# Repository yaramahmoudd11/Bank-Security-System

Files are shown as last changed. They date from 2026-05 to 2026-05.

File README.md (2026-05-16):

# 🏦 Bank Smart Security System

An AI-powered smart security system for banks and restricted areas using embedded systems, machine learning, IoT, cloud services, Docker deployment, and real-time mobile monitoring.

---

## 📸 Project Overview

The **Bank Smart Security System** is designed to automate security monitoring in restricted areas such as bank rooms, storage areas, locker rooms, and sensitive access zones.

The system combines:

* A **Raspberry Pi Linux-based unit** for camera processing, face recognition, server communication, GPIO handling, Docker deployment, and cloud integration.
* A **PIC16F877A microcontroller-based unit** for low-level sensor reading, voltage monitoring, relay control, buzzer control, LED indication, and lock control.
* A **Flutter mobile application** for real-time alerts, door control, voltage visualization, outage statistics, and event review.
* **Supabase** for database, storage, and real-time streams.
* **Firebase Cloud Messaging** for push notifications.
* **HuggingFace** for hosting the trained face-recognition classifier/model files.
* **Docker Hub** for Raspberry Pi deployment.

The system detects unauthorized access, after-hours motion intrusion, and power-fault conditions, then sends real-time alerts to the manager through the mobile application.

---

## 🧠 High-Level System Flow

### Face Recognition Flow

```text
Camera → Face Detection → ArcFace Embedding → SVC Classifier
                                                      |
                                                      v
                                              Known? → Log access
                                              Unknown? → Alert App → User decides action
                                                                          |
                                                                          v
                                                              HTTP request to Pi → Alarm / Lock
```

### Sensor and Power Monitoring Flow

```text
PIR Sensor → PIC16F877A → Close door + Light room → Signal Pi → Capture image → Alert App
Voltage Sensor → PIC16F877A → Power statistics → Raspberry Pi → Alert App
```

---

## ✅ Main Features

* Face recognition access control
* Authorized and unauthorized person classification
* PIR motion detection
* Voltage and power-fault monitoring
* Relay-controlled solenoid lock
* Buzzer and LED alarm indicators
* Raspberry Pi camera evidence capture
* Supabase cloud database integration
* Supabase storage for alert images
* Firebase Cloud Messaging notifications
* Real-time mobile alert streaming
* Remote door lock/unlock control
* Live voltage monitoring and visualization
* Power stability percentage
* Outage rate percentage
* Average voltage display
* Backup battery activity indication
* Alert status tracking: `new` and `reviewed`
* Docker deployment on Raspberry Pi
* HuggingFace-hosted face-recognition model files

---

## 🏗️ Final System Architecture

```text
Camera / Sensors
      |
      v
Raspberry Pi Unit + PIC16F877A Unit
      |
      v
Face Recognition + Sensor Processing
      |
      v
Security Decision Logic
      |
      v
Supabase Database + Supabase Storage
      |
      v
Firebase Cloud Messaging
      |
      v
Flutter Mobile Application
      |
      v
Manager Action:
- View alert
- Review alert
- Lock door
- Unlock door
- Ignore alert
```

---

## 🧩 Hardware Components

### Raspberry Pi / Linux-Based Unit

* Raspberry Pi 4
* Camera module
* Python runtime
* OpenCV
* ONNX face recognition models
* Network connection
* GPIO pins for PIR, power outage signal, alarm, and door lock
* Flask HTTP server interface for lock and alert actions
* Docker runtime for containerized deployment

### PIC16F877A Microcontroller Unit

* PIC16F877A microcontroller
* PIR motion sensor
* Voltage sensor module
* 2-channel relay module
* Solenoid lock
* Buzzer
* LEDs
* Logic level converter
* External power supply
* Backup battery switching circuit

---
## 🗂️ Repository Structure

```text
Bank-Security-System/
│
├── README.md
│
├── demo/
│   ├── demo_video_link.txt
│   └── .gitkeep
│
├── docs/
│   ├── diagrams/
│   ├── references/
│   └── schematics/
│
├── face_systems/
│   ├── main.py
│   ├── down.py
│   └── models/
│
├── hardware/
│   ├── pcb/
│   ├── pic_microcontroller/
│   └── wiring_diagrams/
│
├── mobile_app/
│   └── bank_alert_app/
│       ├── lib/
│       ├── android/
│       ├── ios/
│       ├── assets/images/
│       ├── supabase/
│       ├── test/
│       ├── web/
│       ├── windows/
│       ├── linux/
│       ├── macos/
│       ├── pubspec.yaml
│       └── pubspec.lock
│
└── pi/
    ├── Dockerfile
    ├── requirements.txt
    └── run.sh
```

---

## 🧠 Raspberry Pi 4 Unit

The Raspberry Pi acts as the main intelligent processing unit. It handles camera capture, face recognition, GPIO interaction, mobile app commands, Supabase communication, and alert generation.

### Main Tasks

| Task | Description |
| --- | --- |
| Camera loop | Captures frames continuously using the Pi camera |
| Detection loop | Runs face detection and face recognition |
| GPIO loop | Monitors PIR signal and power outage signal from the PIC |
| Cloud update | Uploads alerts, images, voltage data, and system states to Supabase |
| HTTP server | Receives lock/unlock/alarm commands from the mobile app |

### Flask API Endpoints

| Endpoint | Action |
| --- | --- |
| `GET /alert_action` | Trigger alarm for a short time |
| `GET /lock_on` | Lock the vault/security door |
| `GET /lock_off` | Unlock the vault/security door |

---

## ⚙️ GPIO Pin Map — Raspberry Pi 4

| Pin (BCM) | Role |
| --- | --- |
| GPIO 23 | PIR sensor input |
| GPIO 24 | Power outage signal input from PIC |
| GPIO 18 | Alarm output |
| GPIO 27 | Door lock output |

---

## 🔌 PIC16F877A Microcontroller Unit

The PIC16F877A unit handles low-level embedded control. It reads analog and digital inputs, controls relays, activates alarm outputs, monitors voltage, and controls lock-related outputs.

### PIC Pin Mapping

| PIC Pin | Function |
| --- | --- |
| RA0 / AN0 | Voltage sensor analog input |
| RB1 | PIR motion sensor input / digital security condition |
| RB2 | Additional digital input condition |
| RC6 / TX  | UART transmit to Raspberry Pi |
| RC7 / RX  | UART receive from Raspberry Pi |
| RD0 | Relay / solenoid lock control |
| RD1 | Alarm or status output |
| RD2 | Low-voltage warning output |
| RD3 | Security or motion-related output |
| RD4 | Lock/unlock-related output |

---

## 🧱 PIC Driver-Based Firmware Structure

The PIC firmware is planned to be organized using a driver-based structure for readability and easier debugging.

## 🧪 Embedded Control Logic

### Voltage Monitoring

The voltage sensor is connected to `RA0/AN0`.

If the measured voltage drops below the selected threshold:

* The low-voltage warning output is activated.
* Backup battery indication can be enabled.
* A power-fault condition is triggered.
* The mobile application displays the outage state through cloud updates.

### PIR Motion Detection

If PIR motion is detected in a restricted area:

* The alarm output is activated.
* The Raspberry Pi captures image evidence.
* An intrusion alert is uploaded to Supabase.
* The mobile application receives a real-time notification.

### Lock Control

The solenoid lock is controlled through a relay.

The lock state can be changed by:

* Local embedded logic
* Raspberry Pi decision logic
* Mobile application remote command

---

## 🤖 Machine Learning Pipeline

The system uses camera-based face recognition to detect whether a person is authorized or unauthorized.

### Pipeline

```text
Camera Frame
      |
      v
YuNet Face Detector
      |
      v
Crop Face
      |
      v
ArcFace Embedding Model
      |
      v
512-D Embedding
      |
      v
SVC Classifier
      |
      v
Name / UNKNOWN
```

### Model on HuggingFace

🤗 **HuggingFace Model:** [Hagar633/face-recognition-svc](https://huggingface.co/Hagar633/face-recognition-svc)

### Model Files

| File | Description |
| --- | --- |
| `classifier.pkl` | Trained SVC model saved using joblib |
| `yunet.onnx` | YuNet face detector |
| `w600k_mbf.onnx` | ArcFace embedding model |
| `det_500m.onnx` | Additional detection model |
| `mobilefacenet.onnx` | Lightweight face model |

Download all model files from HuggingFace and place them in the models folder before running.

Recommended model folder:

```text
face_systems/models/
```

### Standalone Classifier Example

```python
import joblib

clf = joblib.load("models/classifier.pkl")
prediction = clf.predict(embedding.reshape(1, -1))
```

Confidence threshold:

```text
0.70
```

Predictions below this threshold are treated as `UNKNOWN`.

---

## 🐳 Docker Setup

### Docker Hub Image

```bash
sudo docker pull hagar633/bank_sys2:latest
```

### Build Locally

```bash
cd raspberry_pi/
sudo docker build -t bank_sys .
```

### Run on Raspberry Pi

```bash
sudo ./run.sh
```

The `run.sh` script mounts Raspberry Pi system libraries and Python virtual environment into the container so hardware dependencies such as `picamera2`, `libcamera`, `GPIO`, and `cv2` can work correctly.

Example run command:

```bash
sudo docker run --privileged --network host \
  -v /dev:/dev \
  -v /run/udev:/run/udev:ro \
  -v /usr:/usr:ro \
  -v /lib:/lib:ro \
  -v /home/pi/venv2:/home/pi/venv2:ro \
  -v /home/pi/bank_sys:/app \
  -e PYTHONPATH=/home/pi/venv2/lib/python3.13/site-packages \
  -e LIBCAMERA_IPA_MODULE_PATH=/usr/lib/arm-linux-gnueabihf/libcamera \
  -e SUPABASE_URL="your_supabase_url" \
  -e SUPABASE_KEY="your_supabase_key" \
  --entrypoint /usr/bin/python3.13 \
  bank_sys /app/mergeall3.py
```

### Push to Docker Hub

```bash
sudo docker login
sudo docker tag bank_sys hagar633/bank_sys2:latest
sudo docker push hagar633/bank_sys2:latest
```

---

## 📦 Dependencies

### Python Dependencies

* `opencv-python` — face detection and embedding preprocessing
* `numpy` — numerical operations
* `scikit-learn` / `joblib` — SVC classifier
* `picamera2` — Raspberry Pi camera interface
* `RPi.GPIO` — GPIO control
* `flask` — HTTP API
* `supabase` — cloud database client
* `requests` — HTTP requests
* `python-dotenv` — environment variables

### System Dependencies

* `libcamera`
* Raspberry Pi OS Bookworm 64-bit
* PIC16F877A with custom firmware
* Docker Engine

---

## 📱 Mobile Application Setup

The mobile application is built using Flutter. It displays alerts, receives notifications, shows voltage statistics, and allows the manager to control the door.

### Required Software

* Flutter SDK
* Android Studio or VS Code
* Android Emulator or Android phone
* Firebase project
* Supabase project

### Installation Steps

Go to the mobile app folder:

```bash
cd Bank-Security-System/mobile_app/bank_alert_app
```

Install dependencies:

```bash
flutter pub get
```

Clean previous builds if needed:

```bash
flutter clean
flutter pub get
```

Run the app:

```bash
flutter run
```

---

## ☁️ Supabase Setup

The app connects to Supabase using:

* Supabase project URL
* Supabase anon key
* `alerts` table
* `door_state` table
* `device_tokens` table
* `voltage sensor` table
* `alerts` storage bucket

### Suggested Tables

#### alerts

| Column | Type | Description |
| --- | --- | --- |
| id | int8 | Alert ID |
| category | text | `access`, `intrusion`, or `power` |
| message | text | Alert message |
| image_path | text | Stored image path |
| source_id  | text | Source unit |
| location | text | Alert location |
| status | text | `new` or `reviewed` |
| created_at | timestamp | Alert creation time |
| extra_data | jsonb | Additional event information |

#### door_state

| Column | Type | Description |
| --- | --- | --- |
| id | int8 | Fixed row ID, usually 1 |
| is_locked | bool | Current lock state |
| updated_at  | timestamp | Last update time |
| updated_by  | text | Source of update |
| last_reason | text | Reason for last state change |

#### device_tokens

| Column | Type | Description |
| --- | --- | --- |
| token | text | FCM device token  |
| platform | text | Device platform |
| updated_at | timestamp | Last token update |

#### voltage sensor

| Column | Type | Description |
| --- | --- | --- |
| id | int8 | Reading ID |
| voltage | float8 | Measured voltage |
| adc_value | int4 | ADC reading |
| status | text | `NORMAL`, `LOW`, or `POWER_OUTAGE` |
| battery_active | bool | Backup battery state |
| created_at | timestamp | Reading time |

---

## 📓 Required Notebook

The final codebase includes:

```text
notebooks/model_finetuning_and_results.ipynb
```

The notebook should document:

* Dataset overview
* Number of enrolled persons
* Number of images per person
* Image preprocessing steps
* Face detection and embedding generation
* Model details
* Recognition threshold
* Similarity score distribution
* Accuracy or evaluation results
* Voltage readings visualization
* Alert category distribution
* Door action statistics
* Inference time analysis
* Power or response-time analysis if measured

---

## ✅ Final Implementation Results

### Access Control

When an unauthorized face is detected:

* The system classifies the person as unauthorized.
* The door remains locked.
* An alert is inserted into the Supabase `alerts` table.
* The captured image is uploaded to Supabase Storage.
* The mobile application displays the alert in the Access tab.
* The manager receives a notification.

### Intrusion Detection

When PIR motion is detected:

* The system triggers an intrusion event.
* Alarm indicators are activated.
* The Raspberry Pi captures image evidence.
* An intrusion alert is sent to the mobile application.
* The manager can review the event and control the door.

### Power Monitoring

When the voltage drops below the defined threshold:

* The PIC detects a low-voltage or outage condition.
* The backup battery indicator is activated.
* A power alert is uploaded to the cloud.
* The mobile app displays the event in the Power tab.
* Live voltage readings are shown in the Voltage tab.

### Mobile Application

The Flutter application provides:

* Splash screen
* Real-time alert list
* Alert details page
* Access alerts tab
* Intrusion alerts tab
* Power alerts tab
* Voltage monitoring tab
* Alert status update
* Door lock/unlock control
* FCM notification support
* Voltage chart
* Power stability percentage
* Outage rate percentage
* Average voltage display
* Battery backup status

---

## 🎬 Demo Scenarios

The following demo scenarios are supported:

1. Authorized user access
2. Unauthorized user detection
3. Motion intrusion detection
4. Power outage detection
5. Remote door lock
6. Remote door unlock
7. Real-time voltage monitoring
8. Mobile notification reception
9. Alert review and status update

---

## 🚀 Running the Full System

### Step 1: Configure Supabase and Firebase

Make sure the following are configured:

* Supabase database tables
* Supabase storage bucket
* Supabase real-time enabled tables
* Firebase Cloud Messaging project
* Flutter Firebase options

### Step 2: Program the PIC

Upload the compiled HEX file to the PIC16F877A.

### Step 3: Start the Raspberry Pi Unit

```bash
cd Bank-Security-System
source venv/bin/activate
python face_systems/main.py
```

### Step 4: Run the Mobile App

```bash
cd mobile_app/bank_alert_app
flutter clean
flutter pub get
flutter run
```

### Step 5: Test the Scenarios

Test the following:

* Face recognition
* Unauthorized access alert
* PIR intrusion alert
* Voltage drop alert
* Door lock command
* Door unlock command
* Notification reception
* Live voltage visualization

---

## 🔐 Security Notes

* Do not publish real Supabase keys, Firebase keys, service account files, or private credentials in a public repository.
* Use `.env` files for local secrets.
* Add secret files to `.gitignore`.
* Use Supabase Row Level Security policies.
* Restrict write access to sensitive tables.
* Validate commands received by the Raspberry Pi before controlling the lock.

Recommended `.gitignore` entries:

```text
.env
*.env
serviceAccountKey.json
firebase-service-account.json
*firebase-adminsdk*.json
google-services.json
GoogleService-Info.plist
node_modules/
__pycache__/
venv/
build/
.dart_tool/
*.log
```

---

## 📚 Documentation

Project documentation is stored in:

```text
docs/
```

It includes:

* System architecture diagram
* Input/output diagram
* Electrical schematic
* PCB documentation
* Reference papers
* Screenshots
* Test results

---

## 🔗 Links

* 🐳 Docker Hub: [hagar633/bank_sys](https://hub.docker.com/r/hagar633/bank_sys2)
* 🤗 HuggingFace Model: [Hagar633/face-recognition-svc](https://huggingface.co/Hagar633/face-recognition-svc)
* 💻 GitHub: [yaramahmoudd11/Bank-Security-System](https://github.com/yaramahmoudd11/Bank-Security-System)

---

## 👥 Authors

* Yara Mahmoud
* Filopater Emad
* Hagar Alsherbiny

---

## 📄 License

This project is developed for educational and academic purposes.

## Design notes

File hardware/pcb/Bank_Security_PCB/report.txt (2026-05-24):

Info: Processing symbol 'C1:Capacitor_THT:C_Disc_D5.0mm_W2.5mm_P5.00mm'.
Info: Processing symbol 'C2:Capacitor_THT:C_Disc_D5.0mm_W2.5mm_P5.00mm'.
Info: Processing symbol 'D1:LED_THT:LED_D5.0mm'.
Info: Processing symbol 'D2:LED_THT:LED_D5.0mm'.
Info: Processing symbol 'J1:Connector_PinHeader_2.54mm:PinHeader_2x20_P2.54mm_Vertical'.
Info: Processing symbol 'J2:Connector_PinHeader_2.54mm:PinHeader_1x03_P2.54mm_Vertical'.
Info: Processing symbol 'J3:Connector_PinHeader_2.54mm:PinHeader_1x03_P2.54mm_Vertical'.
Info: Processing symbol 'J4:Connector_PinHeader_2.54mm:PinHeader_1x03_P2.54mm_Vertical'.
Info: Processing symbol 'J5:TerminalBlock_CUI:TerminalBlock_CUI_TB007-508-02_1x02_P5.08mm_Horizontal'.
Info: Processing symbol 'J7:Connector_PinHeader_2.54mm:PinHeader_1x04_P2.54mm_Vertical'.
Info: Processing symbol 'J9:Connector_PinHeader_2.54mm:PinHeader_1x12_P2.54mm_Vertical'.
Info: Processing symbol 'J10:Connector_PinHeader_2.54mm:PinHeader_1x12_P2.54mm_Vertical'.
Info: Processing symbol 'R1:Resistor_THT:R_Axial_DIN0207_L6.3mm_D2.5mm_P7.62mm_Horizontal'.
Info: Processing symbol 'R2:Resistor_THT:R_Axial_DIN0207_L6.3mm_D2.5mm_P7.62mm_Horizontal'.
Info: Processing symbol 'U1:Package_DIP:DIP-40_W15.24mm'.
Info: Processing symbol 'Y1:Crystal:Crystal_HC49-U_Vertical'.
Add C1 (footprint 'Capacitor_THT:C_Disc_D5.0mm_W2.5mm_P5.00mm').
Add C2 (footprint 'Capacitor_THT:C_Disc_D5.0mm_W2.5mm_P5.00mm').
Add D1 (footprint 'LED_THT:LED_D5.0mm').
Add D2 (footprint 'LED_THT:LED_D5.0mm').
Add J1 (footprint 'Connector_PinHeader_2.54mm:PinHeader_2x20_P2.54mm_Vertical').
Add J2 (footprint 'Connector_PinHeader_2.54mm:PinHeader_1x03_P2.54mm_Vertical').
Add J3 (footprint 'Connector_PinHeader_2.54mm:PinHeader_1x03_P2.54mm_Vertical').
Add J4 (footprint 'Connector_PinHeader_2.54mm:PinHeader_1x03_P2.54mm_Vertical').
Add J5 (footprint 'TerminalBlock_CUI:TerminalBlock_CUI_TB007-508-02_1x02_P5.08mm_Horizontal').
Add J7 (footprint 'Connector_PinHeader_2.54mm:PinHeader_1x04_P2.54mm_Vertical').
Add J9 (footprint 'Connector_PinHeader_2.54mm:PinHeader_1x12_P2.54mm_Vertical').
Add J10 (footprint 'Connector_PinHeader_2.54mm:PinHeader_1x12_P2.54mm_Vertical').
Add R1 (footprint 'Resistor_THT:R_Axial_DIN0207_L6.3mm_D2.5mm_P7.62mm_Horizontal').
Add R2 (footprint 'Resistor_THT:R_Axial_DIN0207_L6.3mm_D2.5mm_P7.62mm_Horizontal').
Add U1 (footprint 'Package_DIP:DIP-40_W15.24mm').
Add Y1 (footprint 'Crystal:Crystal_HC49-U_Vertical').

Info: Total warnings: 0, errors: 0.

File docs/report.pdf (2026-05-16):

## Zewail City of Science and Technology

University of Science and Technology

# Bank Smart Security System

## Embedded Systems Project

Team Members

Yara Mahmoud
Filopater emad
Hagar alsherbiny

Course: Embedded Systems
Date: May 16, 2026

§ GitHub Repository (https://github.com/yaramahmoudd11/Bank-Security-System)

## 1 Introduction

Banks and restricted facilities require reliable and intelligent security systems capable of detecting unauthorized access, monitoring abnormal conditions, and sending immediate alerts. Traditional security systems usually depend on human supervision, passwords, keys, or simple alarm circuits. These methods may fail to provide fast automated response, remote monitoring, or evidence collection during emergencies.
This project presents a smart bank security system integrating embedded systems, machine learning, computer vision, and IoT technologies. The proposed system combines a PIC16F877A microcontroller, Raspberry Pi, camera module, PIR sensor, voltage sensor, relay-controlled solenoid lock, buzzer, LED indicators, cloud services, and a mobile application. The system provides real-time monitoring, automatic safety actions, and remote notifications.
The implemented system can:
- Detect authorized and unauthorized persons using face recognition.
- Monitor motion in restricted areas using a PIR sensor.
- Monitor power conditions using a voltage sensor.
- Automatically control a solenoid door lock through a relay module.
- Trigger local alarms using a buzzer and LED indicators.
- Send real-time alerts and captured images to a mobile application.

## 2 Literature Review

Several recent works have proposed IoT-based security systems using cameras, sensors, cloud communication, and machine-learning methods. These systems show that combining embedded hardware with computer vision can improve access control and intrusion detection compared to traditional lock-and-key or password-based security.
Margapuri et al. proposed PiBase, an IoT-based security system using Raspberry Pi, PIR motion sensor, Pi camera, Android application, and Google Firebase. Their system detects human intrusion using PIR and camera input, applies Haar cascade for face detection and LBPH for face recognition, and sends mobile notifications using Firebase Cloud Messaging. This work is closely related to our project because it combines Raspberry Pi, PIR sensing, camera-based recognition, cloud database services, and mobile alerts [1]. Nguyen et al. proposed a smart security system based on face recognition for authenticated access. Their system architecture includes a camera node, cloud server, smartphone, and smart devices. The Raspberry Pi camera node detects faces and performs image processing using Dlib and TensorFlow, while the cloud server stores data and supports model training. This work supports the use of Raspberry Pi and machine learning for automated access-control systems [2].
Kumar et al. discussed smart face recognition using IoT and machine learning. Their work describes the general pipeline of face recognition systems, including data acquisition, face detection, face alignment, feature extraction, face recognition, and decision making. The paper also highlights the importance of cameras and sensors for real-time smart security applications [3].

Krishnaveni and Karthick proposed an IoT-based bank locker security system with face recognition. Their system uses Raspberry Pi camera-based face recognition as part of a multi-stage authentication process for bank locker access. This paper is directly related to our application domain because it targets bank security and restricted locker access using face recognition and IoT communication [4].
Compared with the reviewed systems, our project combines Raspberry Pi-based face recognition with a PIC16F877A microcontroller for low-level hardware control. The PIC handles sensor readings and actuator control, while the Raspberry Pi handles camera processing, face recognition, and cloud communication. This separation improves modularity and makes the system suitable for both embedded hardware implementation and intelligent monitoring.

## 3 Used Components

Component | Function
PIC16F877A | Main microcontroller for sensor interfacing and actuator control.
Raspberry Pi | Runs camera processing, face recognition, cloud communication, and system logic.
Camera Module | Captures face images and evidence images during intrusion events.
PIR Sensor | Detects motion in restricted areas.
Voltage Sensor Module | Measures power supply condition and sends ana-log output to PIC RA0.
2-Channel Relay Mod-ule | Switches high-power loads such as solenoid lock, alarm, or lighting.
Solenoid Lock | Provides automatic door locking/unlocking.
Logic Level Converter | Converts UART signals between PIC 5V logic and Raspberry Pi 3.3V logic.
Buzzer | Provides audible alarm during unauthorized ac-cess or power fault.
LED Indicators | Show system status such as alert, transmission, or lock state.
Mobile Application | Displays alerts, images, and system status to the manager/user.
Supabase/Firebase | Provides cloud database, image storage, and no-tification support.

Table 1: List of used components and their functions.

## 4 Input/Output Diagram

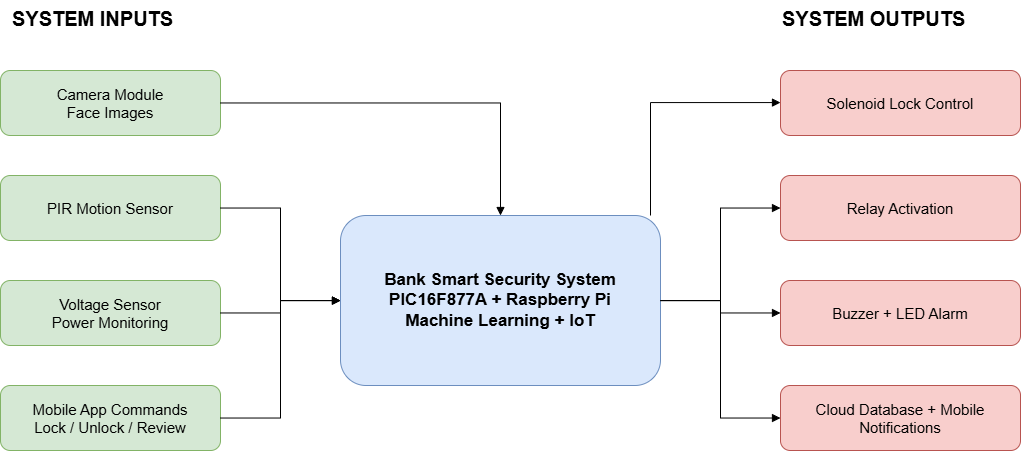
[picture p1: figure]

Figure 1: Input/output diagram of the proposed system.

## 5 System Architecture Schematic

The system architecture consists of two main processing layers. The first layer is the embedded control layer based on the PIC16F877A microcontroller. This layer reads the voltage sensor and PIR sensor and controls output actuators such as the relay, buzzer, and LED. The second layer is the intelligent processing layer based on the Raspberry Pi. This layer runs face recognition, communicates with the cloud database, and sends notifications to the mobile application.
The PIC and Raspberry Pi communicate through UART. Since the PIC operates at 5V logic while the Raspberry Pi operates at 3.3V logic, a logic level converter is used to protect the Raspberry Pi GPIO pins.

Sensors → PIC16F877A ↔ Raspberry Pi → ML Processing → Cloud Database → Mobile App

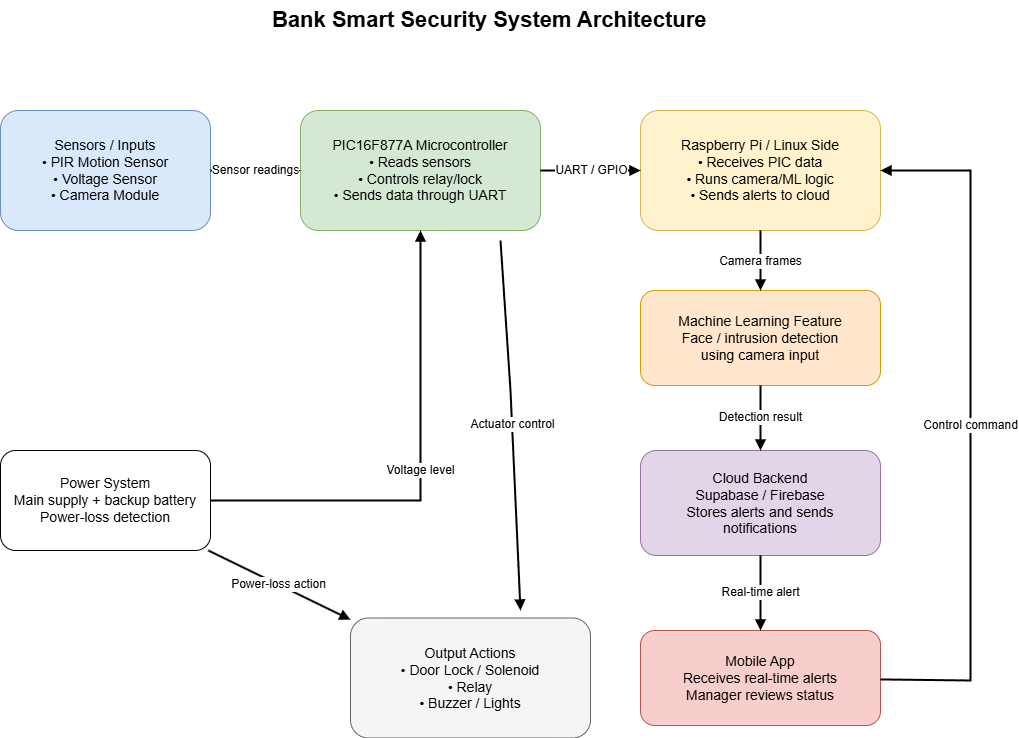
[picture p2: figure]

Figure 2: System architecture schematic.

## 6 Electrical Schematic and PCB Design

The electrical schematic was designed using KiCad. The design includes the PIC16F877A, Raspberry Pi header, 12-pin logic level converter, 2-channel relay module, solenoid lock connector, PIR sensor connector, voltage sensor connectors, buzzer, LED indicators, crystal oscillator, and power connectors.
The main electrical connections are:
- Voltage sensor output connected to PIC RA0.
- PIR sensor output connected to PIC RB1.
- Relay input connected to PIC RD0.
- Relay input 2 connected to PIC RD2.
- Buzzer/LED status connected to PIC RD3.
- PIC UART TX/RX connected to Raspberry Pi UART through the logic level converter.
- Relay output terminals connected to the solenoid lock power path.
- Common ground is shared between PIC, Raspberry Pi, sensors, relay module, and power supplies.
- Logic convertor was used for uart comminucation and upconverting or downconverting 3.3 V and 5 V.

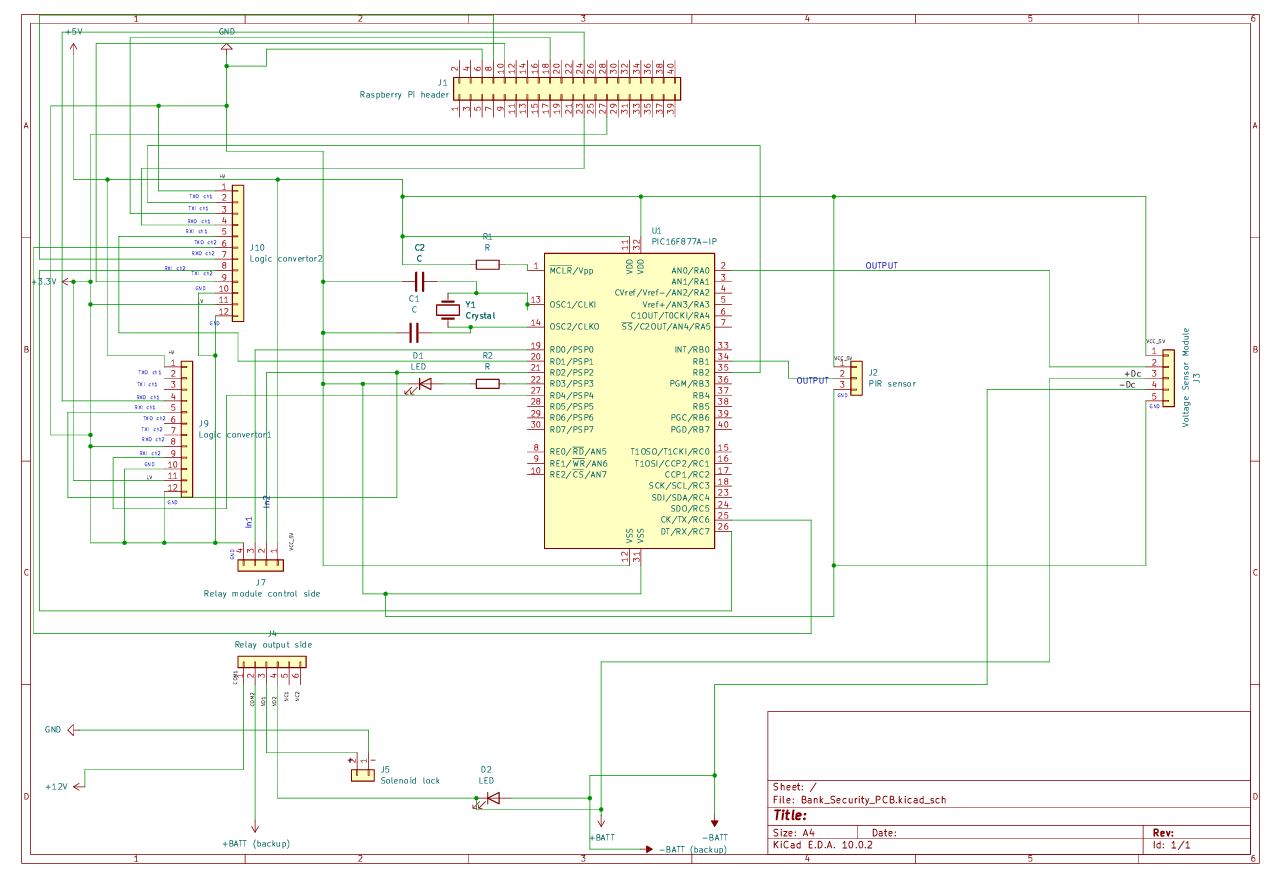
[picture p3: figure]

Figure 3: Electrical schematic designed in KiCad.

## 7 Implemented Safety-Critical Features

### 7.1 Feature 1: Face Recognition Access Control

The Raspberry Pi camera captures a face image and runs the face recognition pipeline. If the detected person is authorized, the system allows access. If the person is unknown or unauthorized, the door remains locked and an alert is sent to the mobile application.

Pseudocode

Start camera
Capture image frame
Detect face in the image
Generate face embedding
Compare embedding with registered database

IF face is recognized as authorized THEN Send unlock command
Deactivate alarm
Log authorized access
ELSE
Keep solenoid lock closed
Activate buzzer and LED alert Capture evidence image
Upload alert to cloud database Send mobile notification
END IF

### 7.2 Feature 2: Intrusion Detection Using PIR Sensor

The PIR sensor monitors motion inside restricted areas. If motion is detected after working hours or while the area is locked, the system treats the event as a possible intrusion.

Pseudocode

Read PIR sensor output

IF PIR output is HIGH THEN
Send motion event to Raspberry Pi Turn on LED indicator
Activate buzzer
Capture image using camera
Upload image and alert details to cloud Send intrusion notification to mobile app END IF

### 7.3 Feature 3: Voltage Monitoring and Power Protection

The voltage sensor measures the supply voltage. If the measured voltage drops below a defined threshold, the system generates a power warning and triggers the backup response.

Pseudocode

Read analog voltage from RA0 Convert ADC value to voltage level

IF voltage is below threshold THEN
Activate warning LED
Activate buzzer
Send power fault message to Raspberry Pi Upload power warning to cloud database Notify mobile application
ELSE
Continue normal operation
END IF

### 7.4 Feature 4: User Door Locking and Unlocking

This feature allows the user or manager to control the door lock remotely from the mobile application. The command is sent to the Raspberry Pi, then forwarded to the PIC microcontroller, which controls the relay connected to the solenoid lock.

Pseudocode

Wait for command from mobile application

IF command == " LOCK " THEN
Raspberry Pi sends LOCK command to PIC through UART PIC activates relay state for locked mode
Solenoid lock keeps the door locked
Update door status in cloud database
Display " Door Locked " on mobile app

ELSE IF command == " UNLOCK " THEN
Raspberry Pi sends UNLOCK command to PIC through UART PIC changes relay state for unlocked mode
Solenoid lock releases the door
Update door status in cloud database
Display " Door Unlocked " on mobile app

END IF

## 8 Implementation Phase

The implementation phase included hardware assembly, embedded programming, Raspberry Pi software development, face recognition model integration, cloud database setup, and mobile application implementation.

### 8.1 Hardware Implementation

- PIC16F877A was used for low-level control.
- Sensors were connected to PIC input pins.
- Relay module was connected to PIC output pins.
- Raspberry Pi was connected to the camera and cloud services.
- Logic level converter was used for safe UART communication.

### 8.2 Software Implementation

- PIC firmware reads sensor values and controls actuators.
- Raspberry Pi code processes camera input and runs face recognition.
- Cloud database stores alerts, images, timestamps, and device status.
- Mobile application displays real-time alerts and system updates.

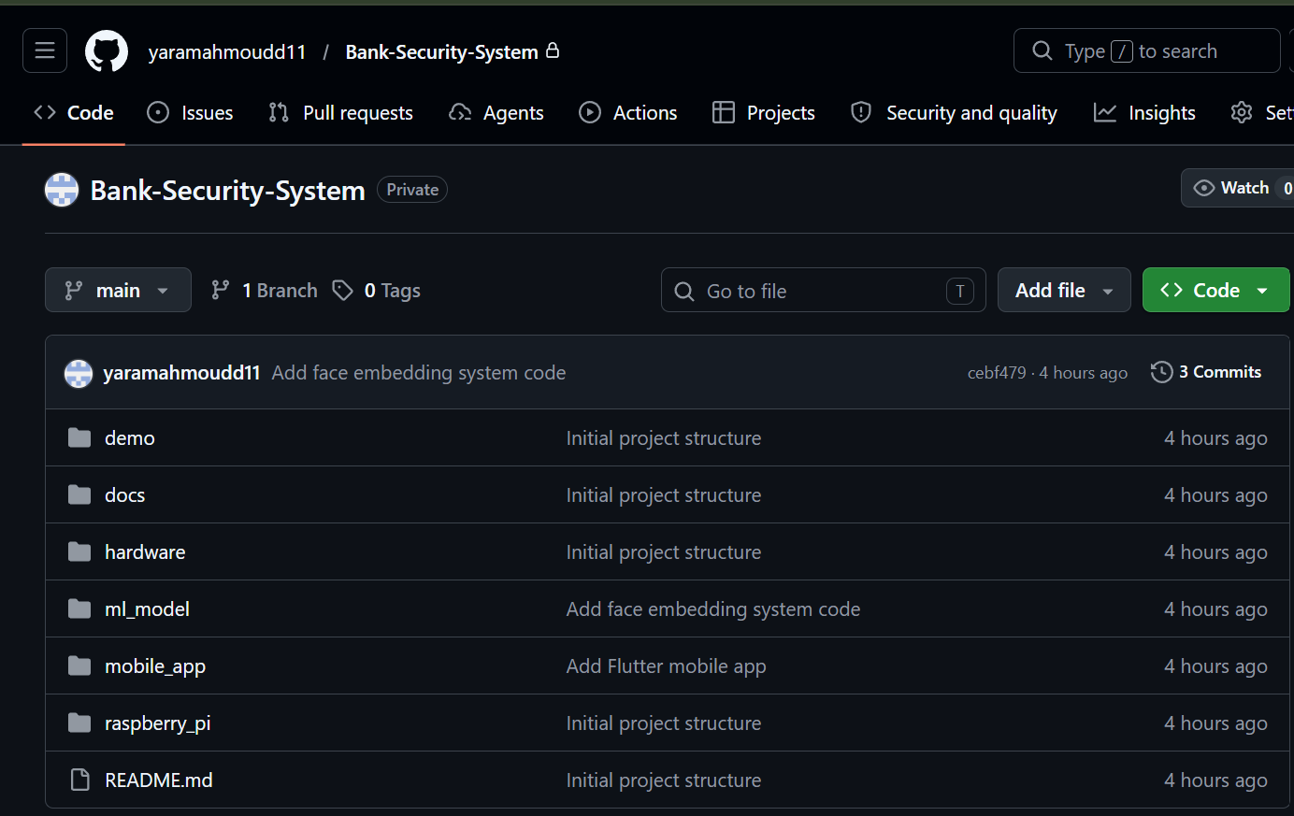
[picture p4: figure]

Figure 4: Documented and replicable codebase.

## 9 Integration Phase

The integration phase connected all modules into one complete system. Sensor readings from the PIC were sent to the Raspberry Pi through UART. The Raspberry Pi processed camera images, checked the recognition result, updated the cloud database, and triggered notifications to the mobile application. The output actions such as door locking, buzzer activation, and LED status were controlled through the relay and PIC output pins. Testing was performed to verify:

- Correct PIR motion detection.
- Correct voltage sensor reading.
- Correct UART communication between PIC and Raspberry Pi.
- Correct face recognition response.
- Correct relay and solenoid lock operation.
- Correct mobile notification delivery.

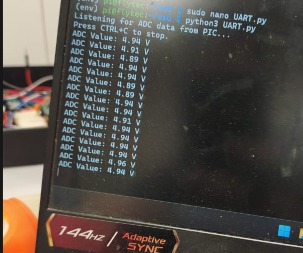
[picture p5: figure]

Figure 5: PIC to Raspberry Pi communication test.

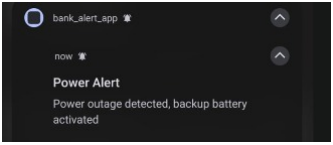
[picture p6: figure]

Figure 6: Mobile application alert display.

## 10 Demo Phase

The demo phase validates the full system operation under realistic scenarios.

### 10.1 Demo Scenario 1: Authorized Access

1. Authorized person stands in front of the camera.
2. The Raspberry Pi recognizes the face.
3. The system allows access and keeps alarm outputs inactive.

### 10.2 Demo Scenario 2: Unauthorized Person

1. Unknown person appears in front of the camera.
2. The system classifies the face as unauthorized.
3. The solenoid lock remains locked.
4. Mobile application receives an alert with image evidence.

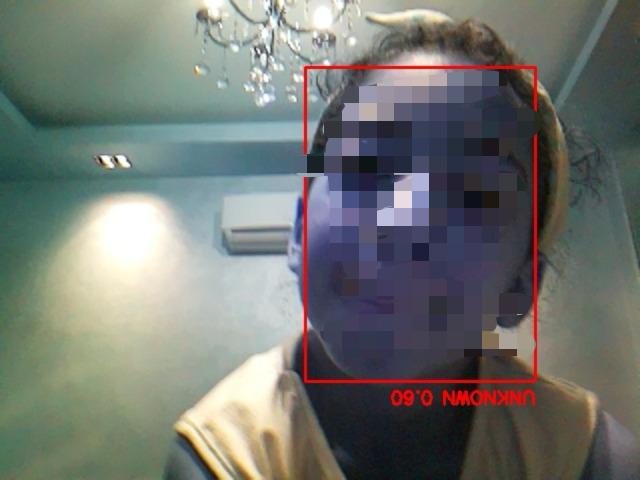
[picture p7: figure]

Figure 7: Unauthorized access demo.

### 10.3 Demo Scenario 3: Motion Detection

1. PIR sensor detects motion in the restricted area.
2. Raspberry Pi captures an image.
3. The system turns on the lights.
4. Alert is uploaded to the cloud and shown in the mobile application.
5. the camera takes a pic of the intrusion location and sends it to the end user.

### 10.4 Demo Scenario 4: Power Fault Detection

1. Voltage drops below the threshold.
2. PIC detects the fault using ADC reading.
3. Warning output is activated.
4. Mobile application receives a power alert.

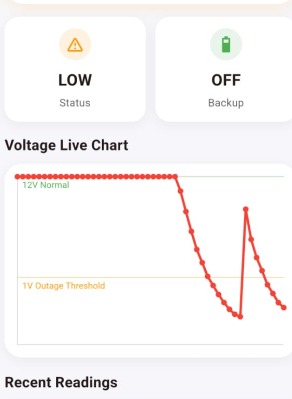
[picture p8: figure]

Figure 8: Power monitoring demo.

## 11 Conclusion

This project demonstrates an intelligent bank security system that combines embedded systems, IoT, cloud communication, and machine learning. The system detects unauthorized access, monitors motion and power conditions, controls a solenoid lock, and sends real-time alerts to a mobile application.
The design improves safety by combining automatic hardware response with remote monitoring. The use of a PIC microcontroller for hardware control and Raspberry Pi for machine-learning processing makes the system modular, practical, and suitable for safety-critical applications.

## References

[1] V. Margapuri, N. Penumajji, and M. Neilsen, “PiBase: An IoT-based Security System Using Google Firebase and Raspberry Pi,” 2021.
[2] T. Nguyen, B. Lakshmanan, and W. Sheng, “A Smart Security System with Face Recognition,” arXiv preprint arXiv:1812.09127, 2018.
[3] A. Kumar, S. Kalumbi, M. K. Gupta, and P. Rao, “Smart Face Recognition Using IoT and Machine Learning,” International Journal of Research Publication and Reviews, vol. 4, no. 5, pp. 4161–4171, 2023.
[4] K. A. Krishnaveni and K. Myilavahanan, “IoT based Bank Locker Security System with Face Recognition,” Grenze International Journal of Engineering and Technology, 2023.

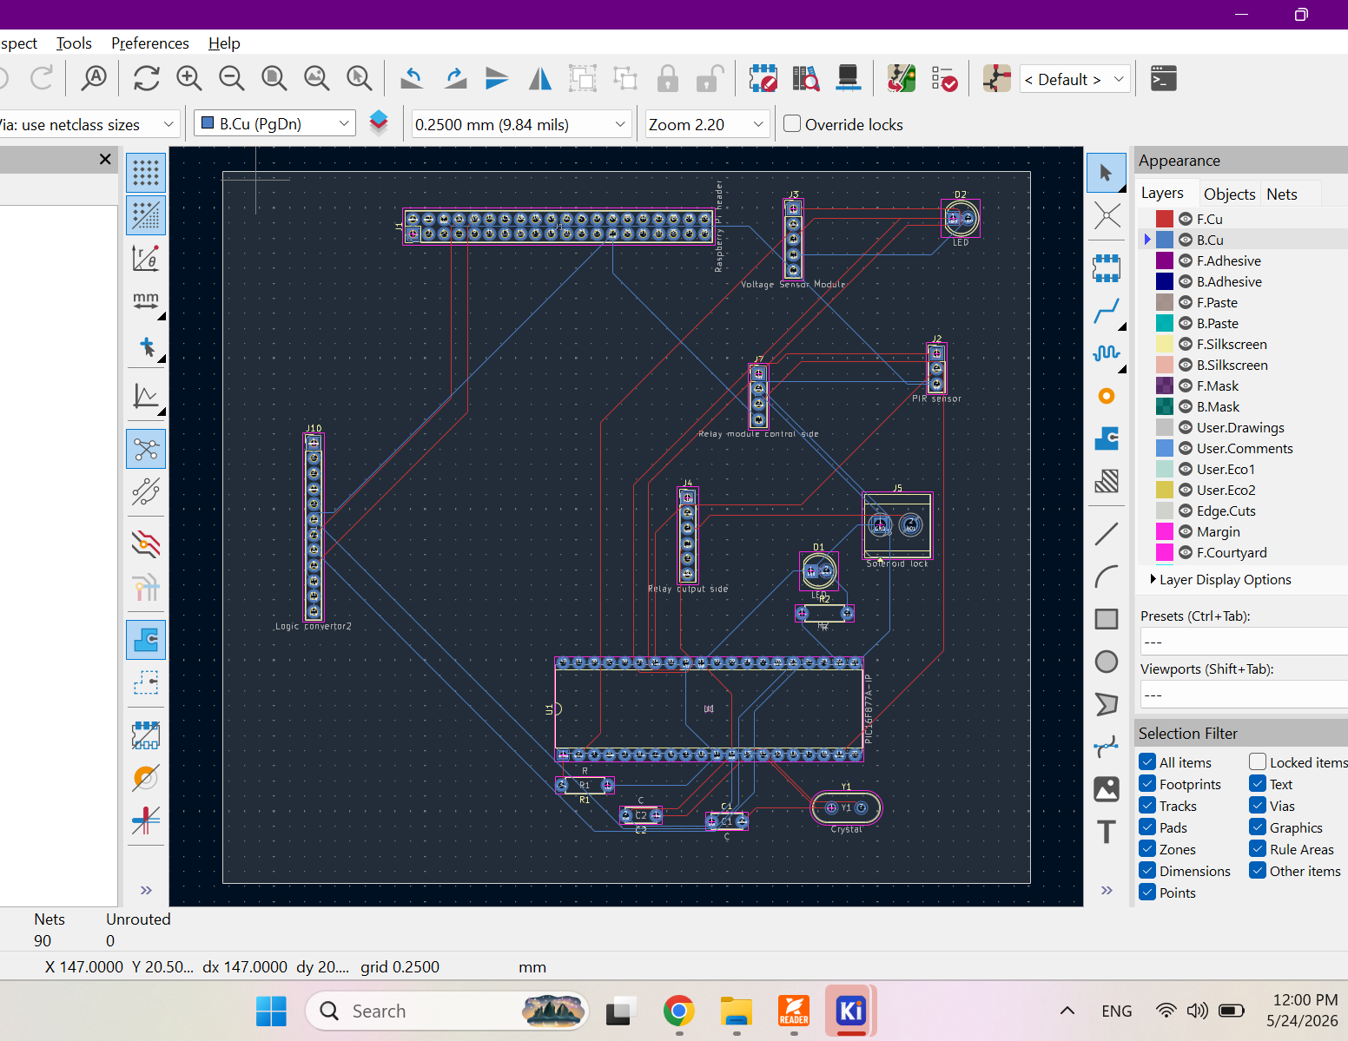
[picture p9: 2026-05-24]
hardware/pcb/Screenshot 2026-05-24 120034.png

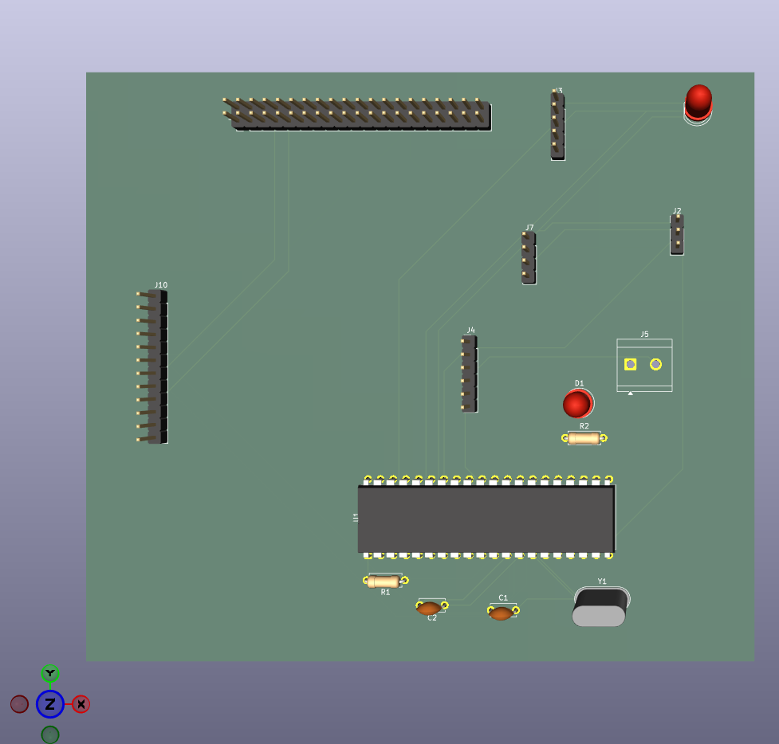
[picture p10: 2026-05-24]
hardware/pcb/Screenshot 2026-05-24 120016.png

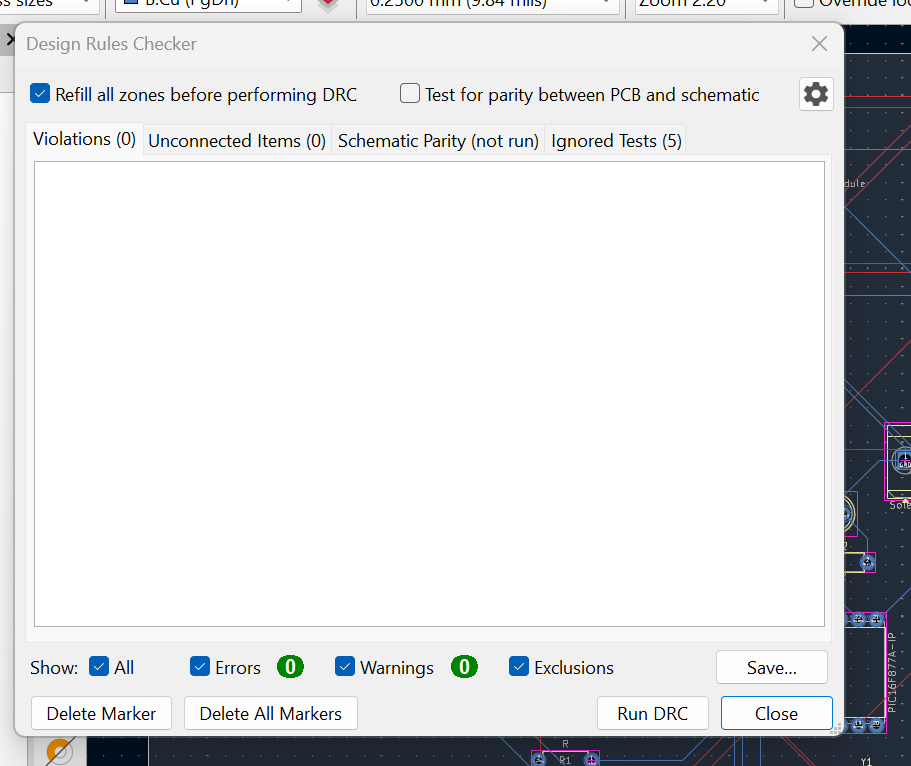
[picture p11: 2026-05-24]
hardware/pcb/Screenshot 2026-05-24 120132.png

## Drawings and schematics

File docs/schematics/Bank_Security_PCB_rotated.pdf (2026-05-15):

2

3

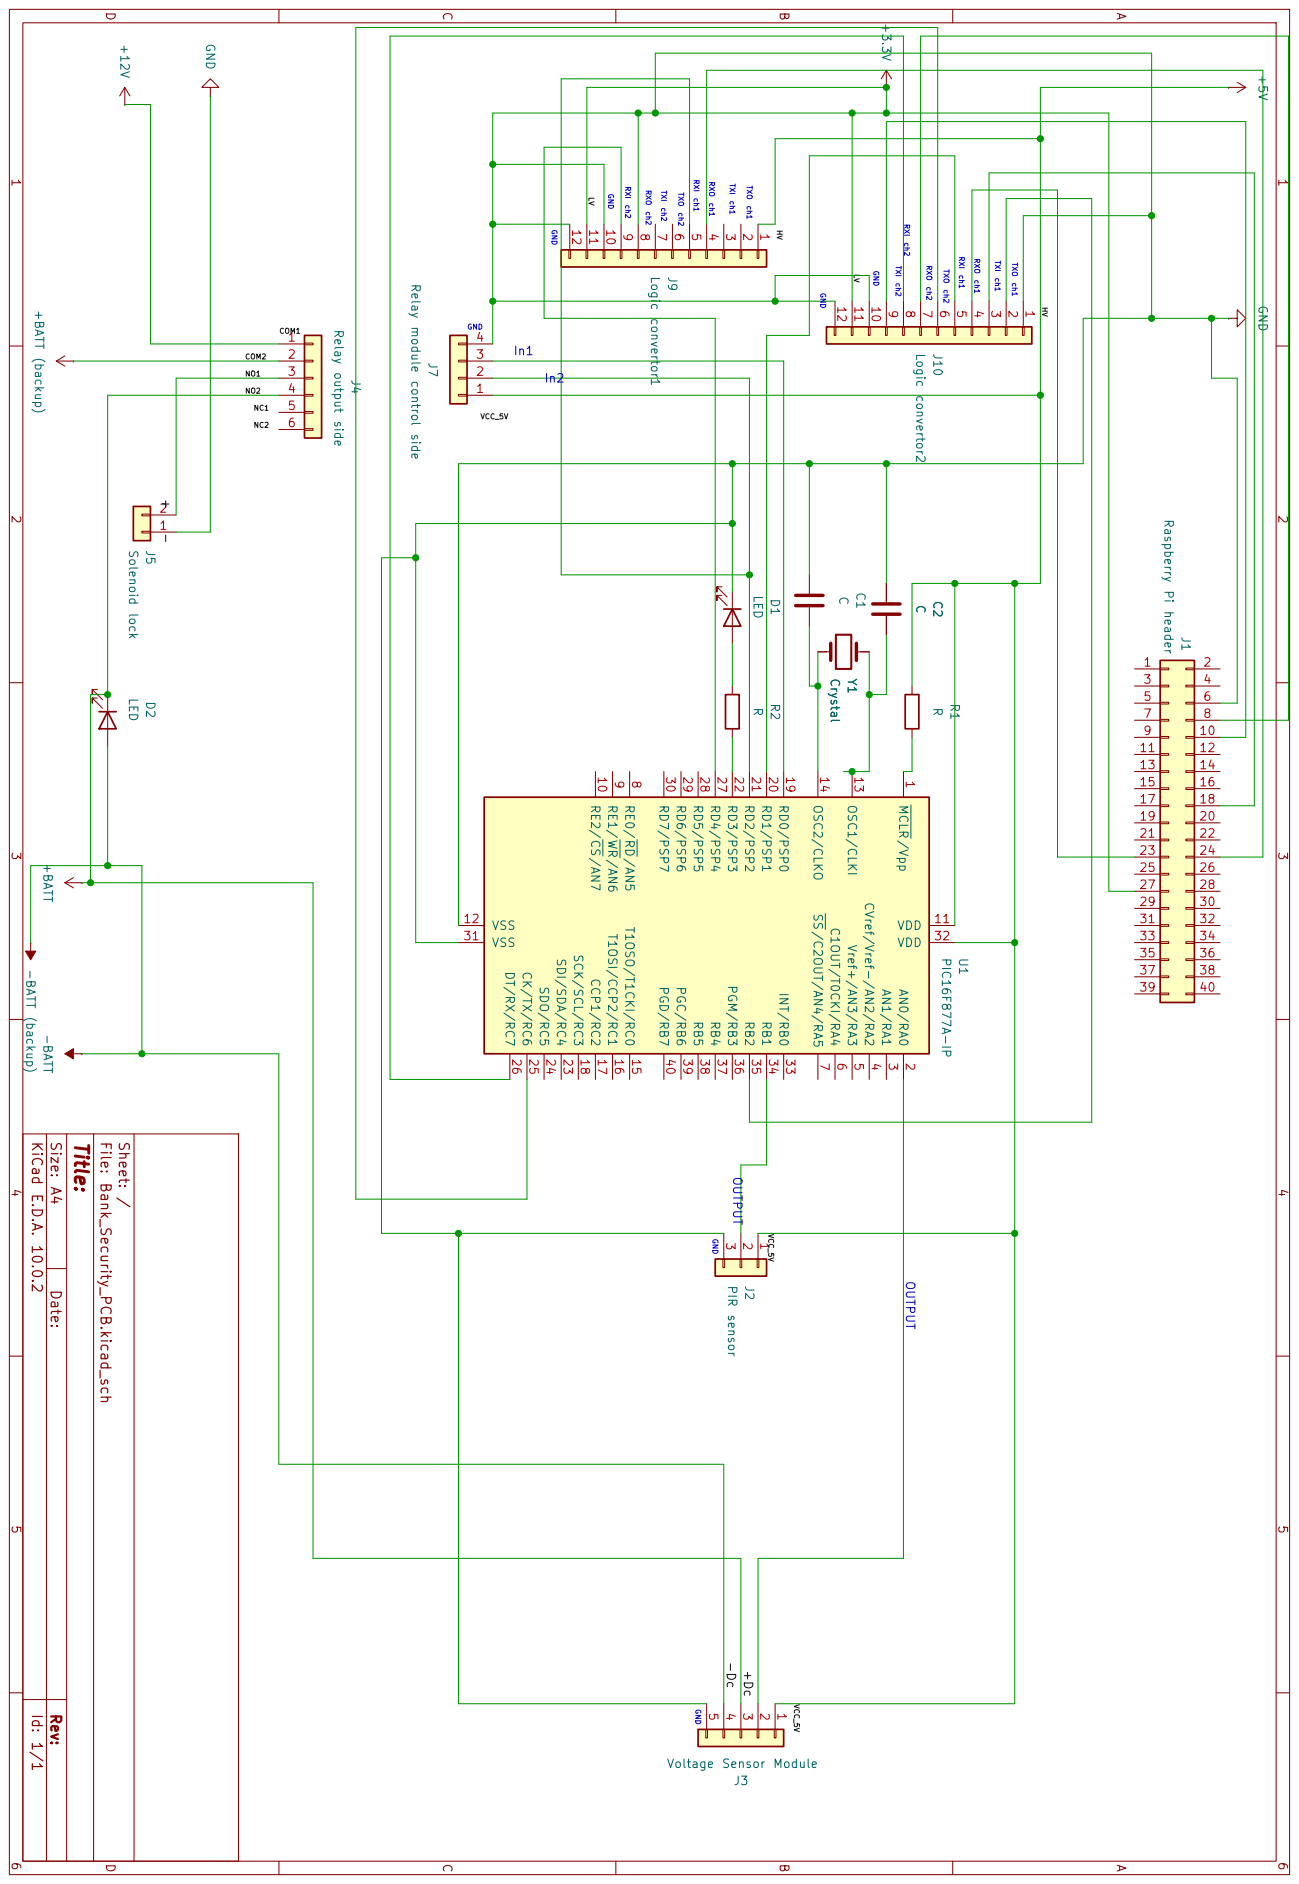
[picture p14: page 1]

RXO ch2 RXI ch1 RXI ch2 GND

TXO ch2 GND OUTPUT OUTPUT

J7 Relay module control side 1

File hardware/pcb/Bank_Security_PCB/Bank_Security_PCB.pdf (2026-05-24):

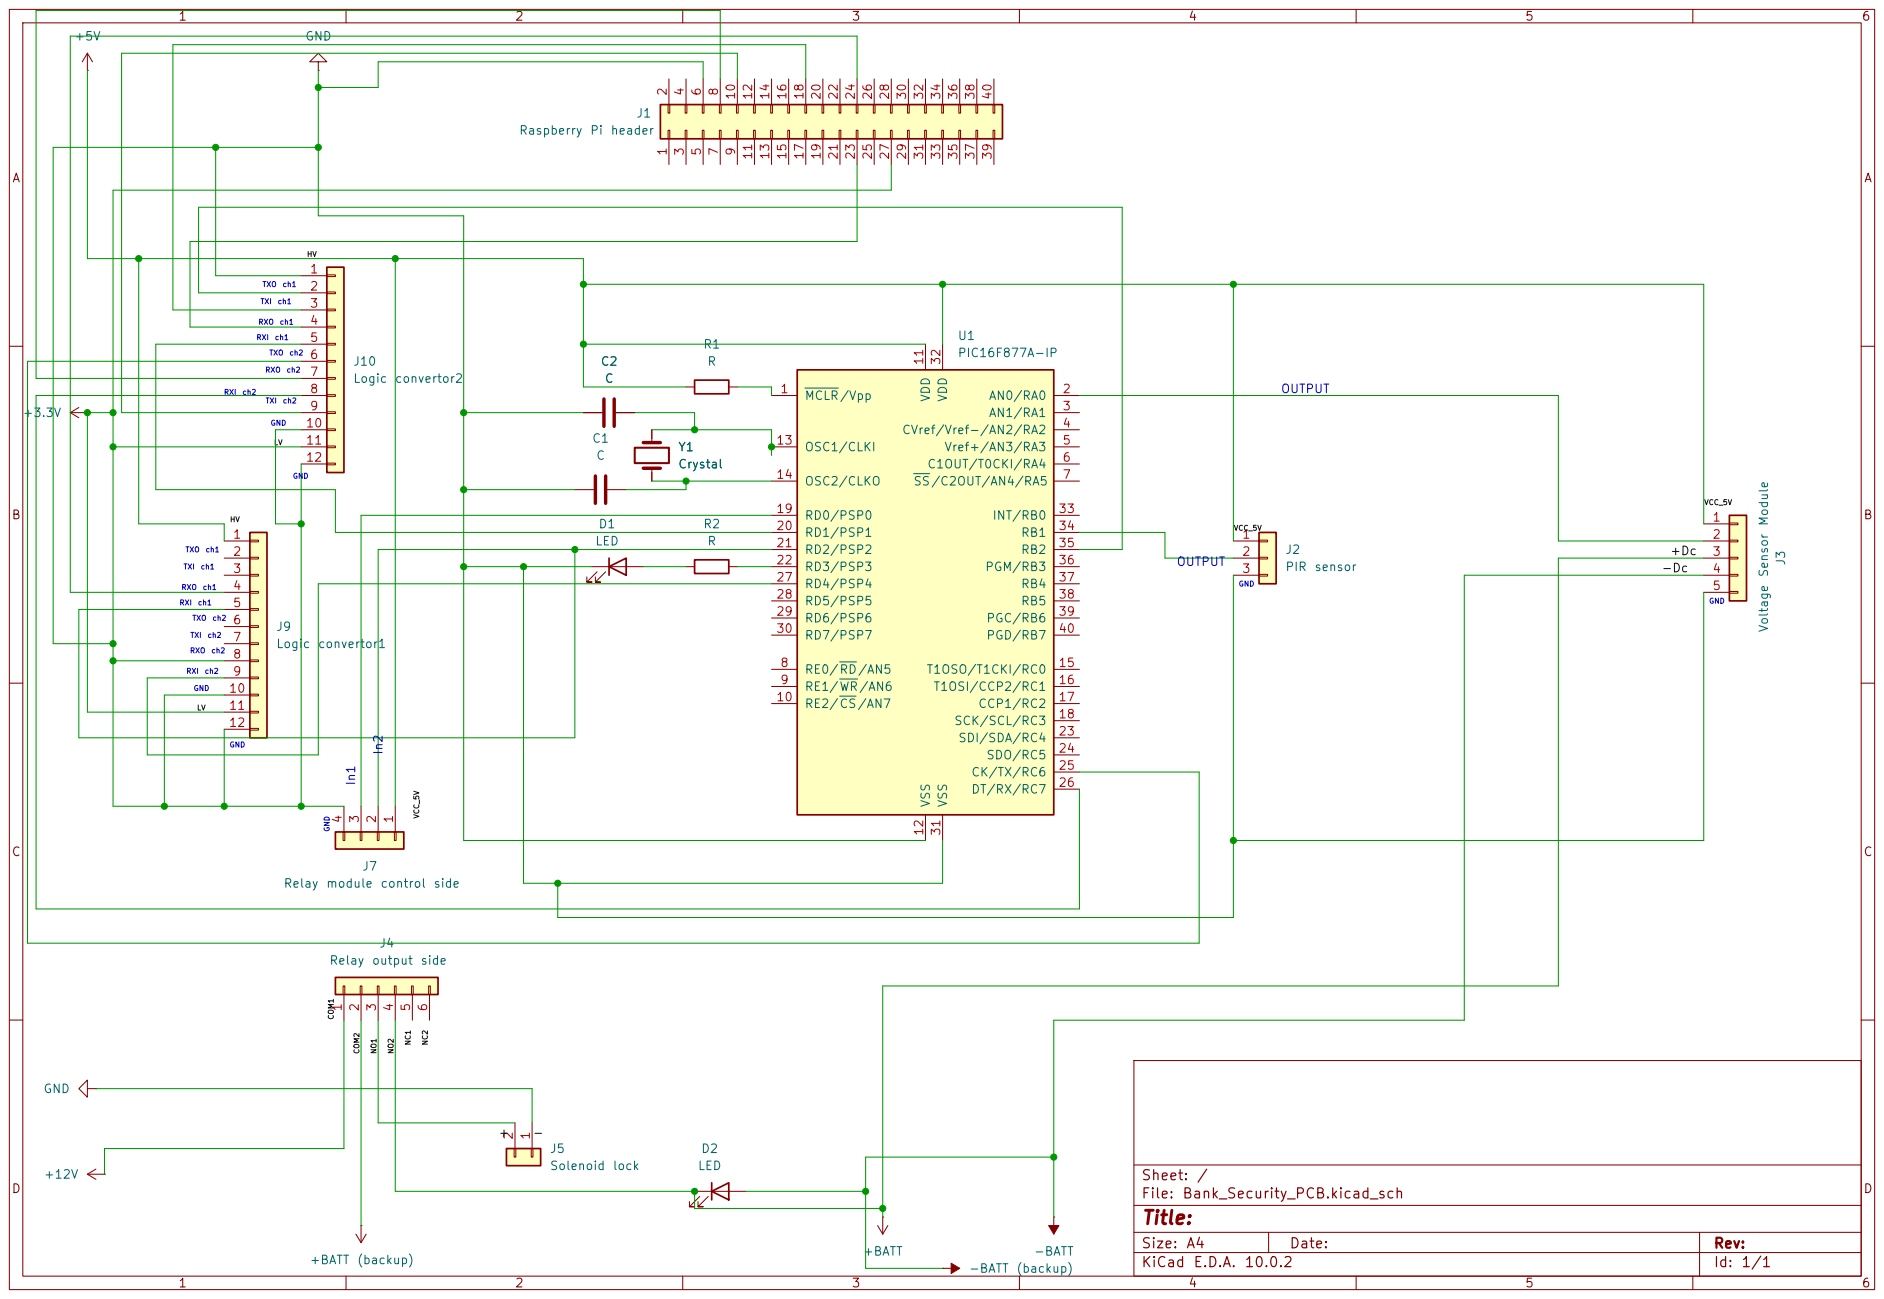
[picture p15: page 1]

RXO ch2 7

6 TXI ch2

Size: A4 | Rev:
KiCad E.D.A. 10.0.2 | Id: 1/1

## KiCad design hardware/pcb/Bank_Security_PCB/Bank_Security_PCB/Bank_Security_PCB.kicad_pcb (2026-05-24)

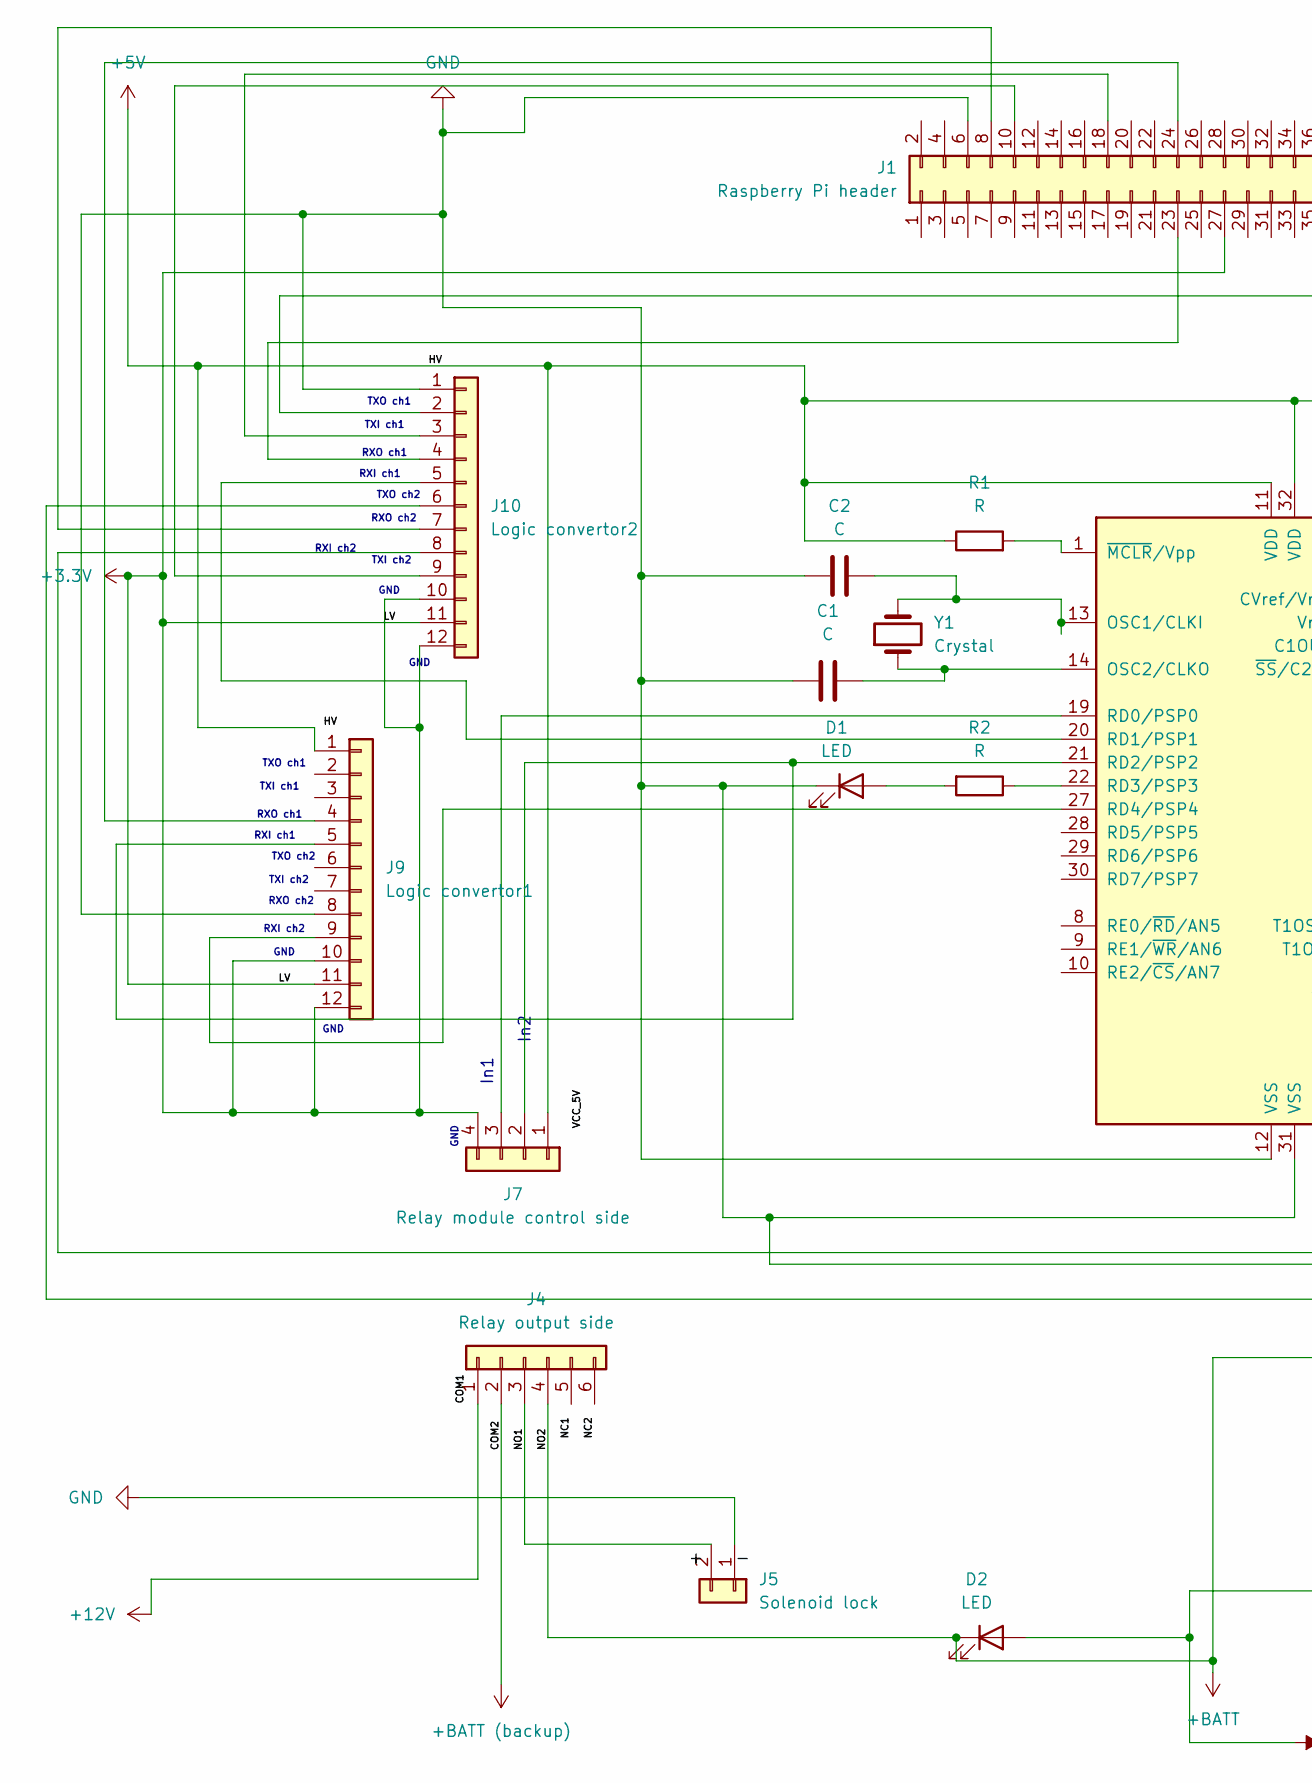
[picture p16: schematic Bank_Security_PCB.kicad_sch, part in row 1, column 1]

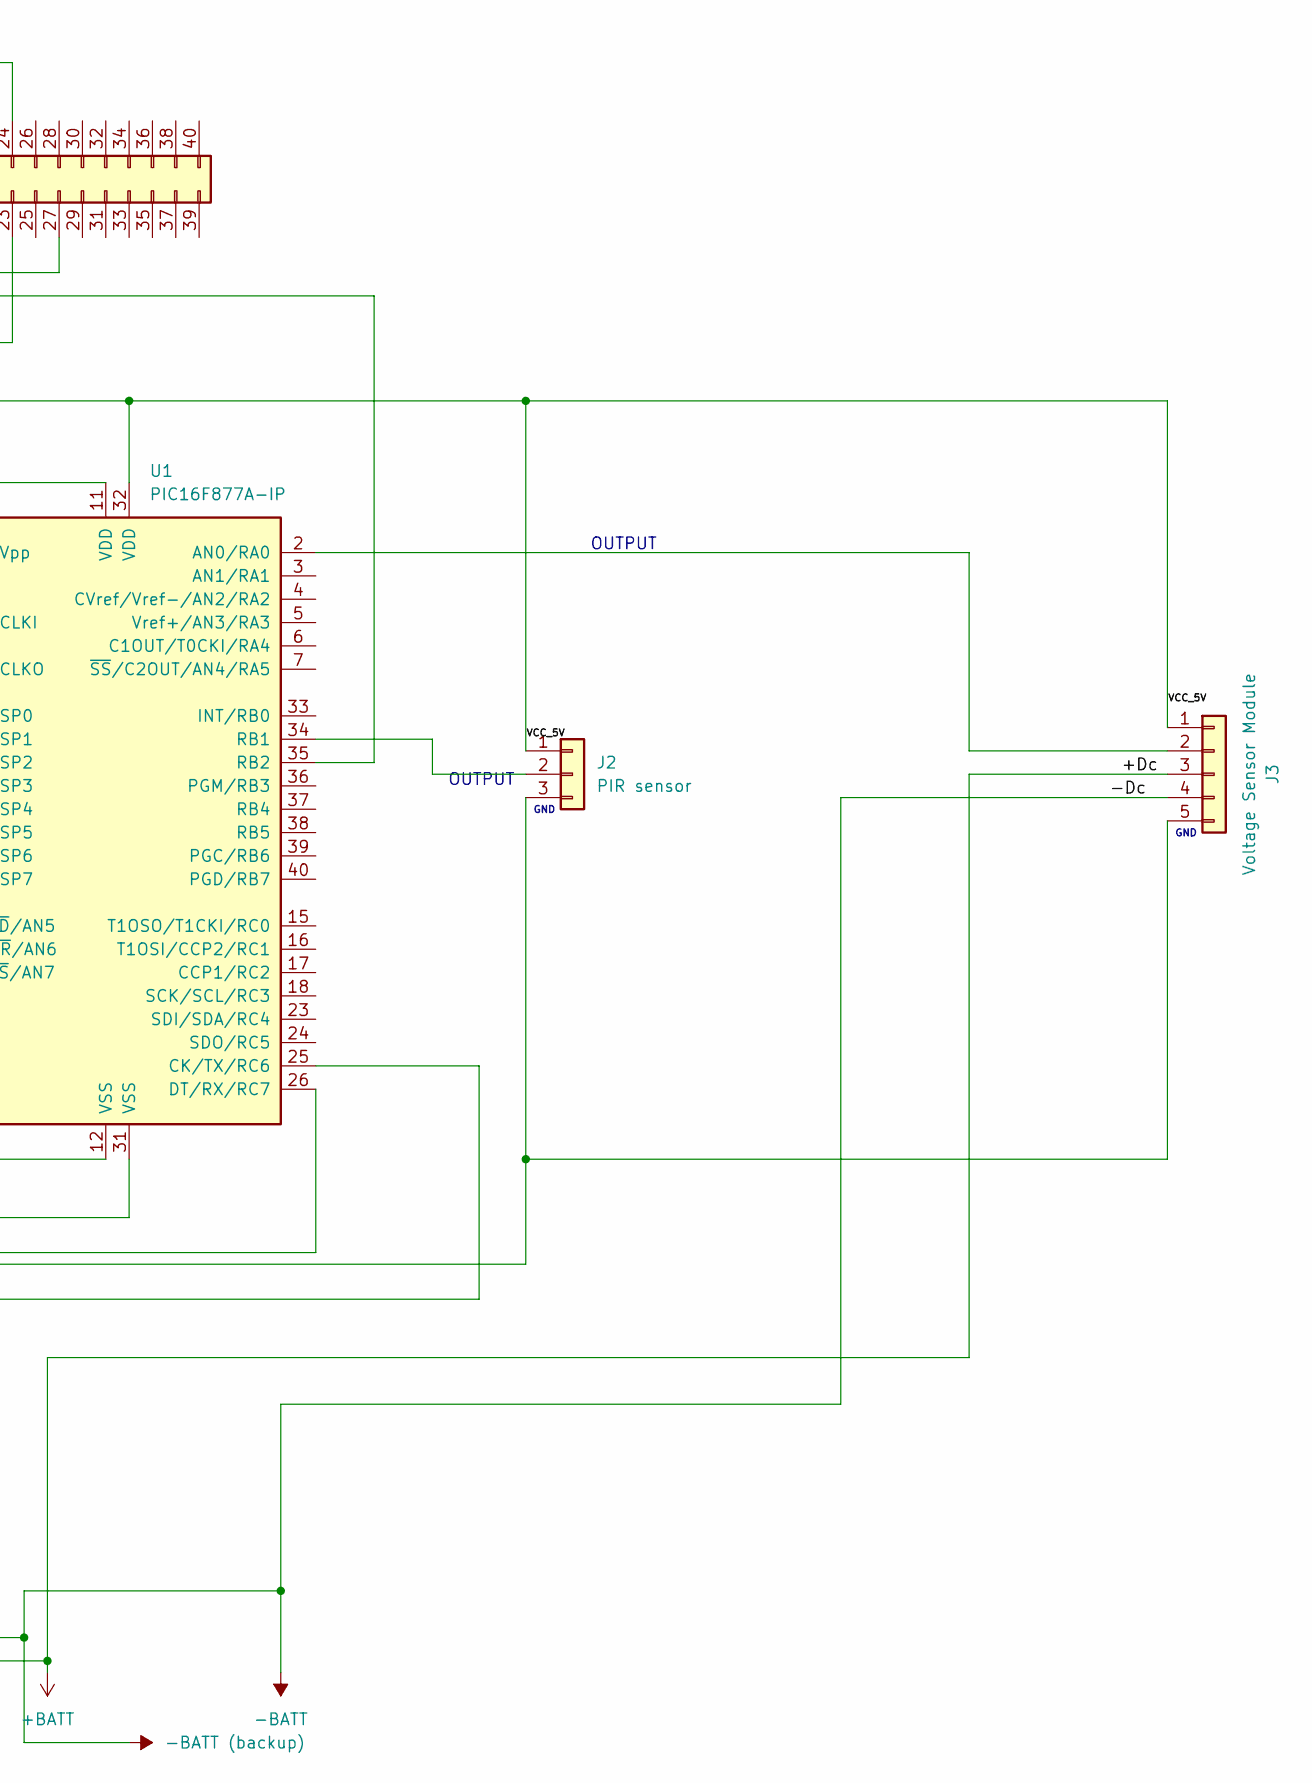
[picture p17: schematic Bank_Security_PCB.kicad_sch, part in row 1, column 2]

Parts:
C1, C2: C; C_Disc_D5.0mm_W2.5mm_P5.00mm
D1, D2: LED; LED_D5.0mm
J1: Raspberry Pi header; PinHeader_2x20_P2.54mm_Vertical
J2: PIR sensor; PinHeader_1x03_P2.54mm_Vertical
J3: Voltage Sensor Module; PinHeader_1x05_P2.54mm_Vertical
J4: Relay output side; PinHeader_1x06_P2.54mm_Vertical
J5: Solenoid lock; TerminalBlock_CUI_TB007-508-02_1x02_P5.08mm_Horizontal
J7: Relay module control side; PinHeader_1x04_P2.54mm_Vertical
J9: Logic convertor1; PinHeader_1x12_P2.54mm_Vertical
J10: Logic convertor2; PinHeader_1x12_P2.54mm_Vertical
R1, R2: R; R_Axial_DIN0207_L6.3mm_D2.5mm_P7.62mm_Horizontal
U1: PIC16F877A-IP; DIP-40_W15.24mm
Y1: Crystal; Crystal_HC49-U_Vertical

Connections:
+3.3V: J1.27, J7.4, J9.10, J9.11, J9.12, J10.10, J10.11, J10.12
+5V: J2.1, J3.1, J7.1, J9.1, R1.1, U1.11 (VDD), U1.32 (VDD)
+12V: J4.1
+BATT: D2.1 (K), J3.3, J4.4
+BATT (backup): J4.2
-BATT: D2.2 (A), J3.4
/NO1: J4.3, J5.2
GND: C1.1, C2.2, D1.1 (K), J1.6, J2.3, J3.5, J5.1, J9.8, J10.1, U1.12 (VSS), U1.31 (VSS)
unnamed: D1.2 (A), R2.2
unnamed: J1.8, J10.7
unnamed: J1.10, J10.9
unnamed: J1.18, J10.3
unnamed: J1.23, J10.4
unnamed: J1.24, J9.4
unnamed: J2.2, U1.34 (RB1)
unnamed: J3.2, U1.2 (AN0/RA0)
unnamed: J7.2, J9.5, U1.21 (RD2/PSP2)
unnamed: J7.3, U1.19 (RD0/PSP0)
unnamed: J9.9, U1.27 (RD4/PSP4)
unnamed: J10.2, U1.35 (RB2)
unnamed: J10.5, U1.20 (RD1/PSP1)
unnamed: J10.6, U1.25 (CK/TX/RC6)
unnamed: J10.8, U1.26 (DT/RX/RC7)
unnamed: C2.1, U1.13 (OSC1/CLKI), Y1.2
unnamed: C1.2, U1.14 (OSC2/CLKO), Y1.1
unnamed: R2.1, U1.22 (RD3/PSP3)
unnamed: R1.2, U1.1 (~MCLR/Vpp)

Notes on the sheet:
RXI ch2
TXI ch2
In2
TXO ch2
TXO ch1
GND
OUTPUT
RXI ch1
TXI ch1
RXO ch1
RXO ch2
In1

Board: 2 copper layers, 16 parts (0 on the bottom side), 25 nets, no tracks yet.

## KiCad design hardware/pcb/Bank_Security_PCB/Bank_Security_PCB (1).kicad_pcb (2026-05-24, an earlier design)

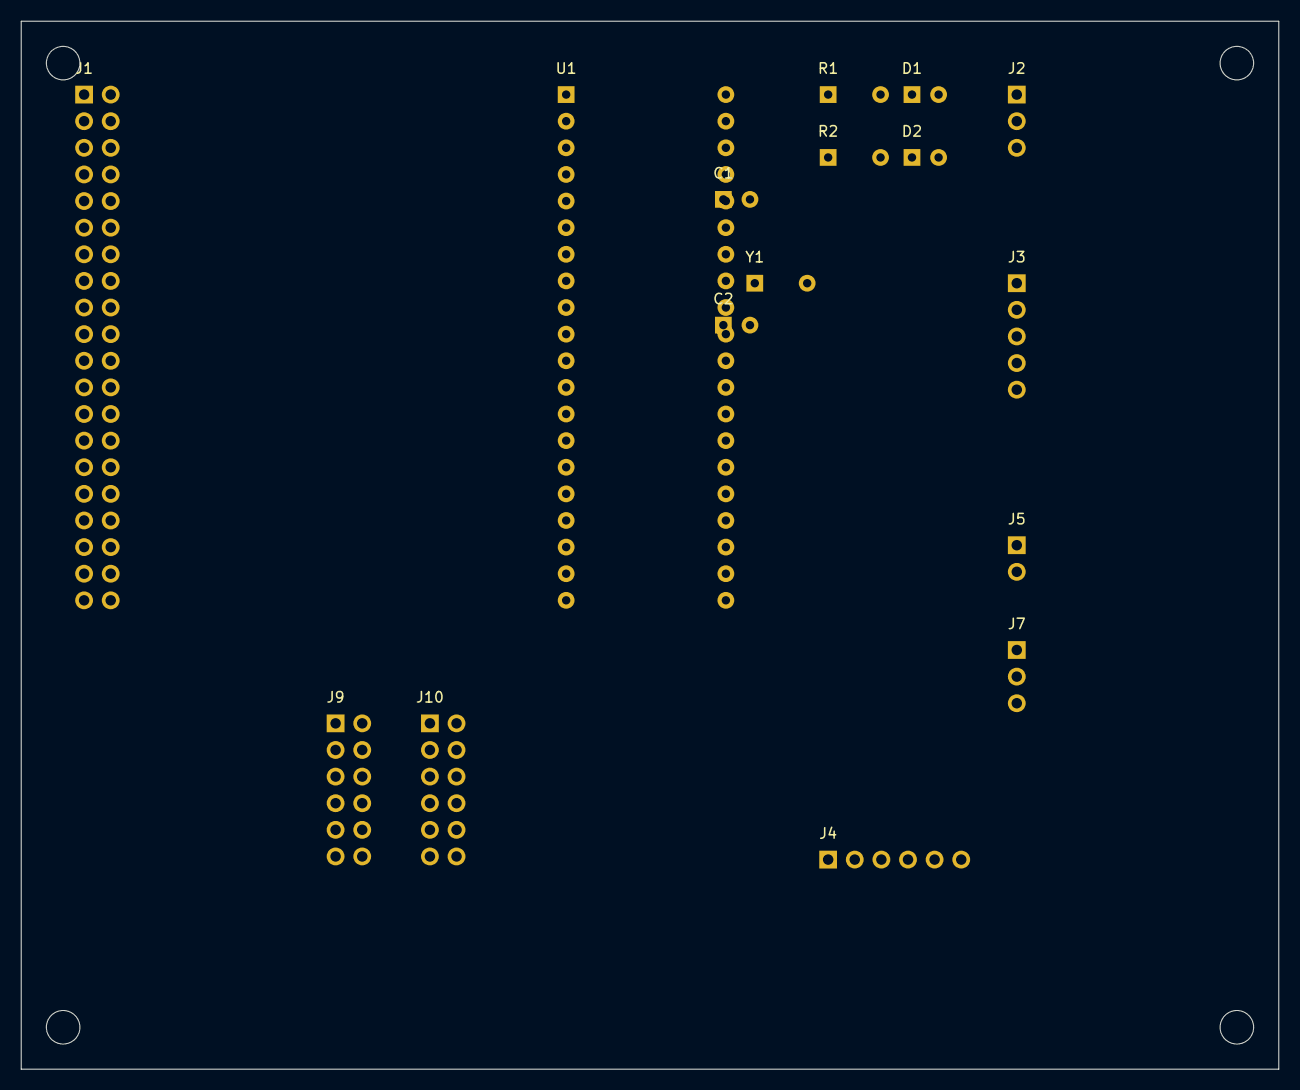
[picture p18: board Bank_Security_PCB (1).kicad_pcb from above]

Board: 2 copper layers, 120.0 x 100.0 mm, 20 parts (0 on the bottom side), 13 nets, no tracks yet.

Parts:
C1, C2: C_100nF
D1, D2: LED
J1: RPi_Header_40
J2: PIR_Sensor
J3: VoltageSensor
J4: RelayOut
J5: Solenoid
J7: RelayCtrl
J9: LogicConv1
J10: LogicConv2
MH: MountingHole
MH#2, MH#3, MH#4: MountingHole
R1, R2: R_330ohm
U1: PIC16F877A-IP
Y1: Crystal_HC49S

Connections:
+3V3: J1.1, J1.17, J9.1, J10.1
+12V: J3.1, J9.2, J10.2
/LED1: D1.1, R1.2
/LED2: D2.1, R2.2
/OSC1: U1.13, Y1.1
/OSC2: U1.14, Y1.2
/RC3_SCL: J1.28, U1.18
/RC4_SDA: J1.27, U1.23
/RC6_TX: J1.8, J9.5, J9.8, J10.5, J10.8, U1.25
/RC7_RX: J1.10, J9.6, J9.7, J10.6, J10.7, U1.26
/SOLENOID: J4.3, J4.4, J5.1
GND: C1.2, C2.2, D1.2, D2.2, J1.6, J1.14, J1.20, J1.25, J1.34, J1.39, J2.2, J3.2, J4.2, J5.2, J7.2, J9.3, J9.4, J9.11, J9.12, J10.3, J10.4, J10.11, J10.12, U1.12, U1.31
VDD: C1.1, C2.1, J1.2, J1.4, J4.1, J7.1, R1.1, R2.1, U1.11, U1.32

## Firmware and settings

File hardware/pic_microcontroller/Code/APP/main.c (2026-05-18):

/******************************************************************************
* @file main.c
* @brief PIC16F877A Security + Voltage Control - Driver Format
* @target PIC16F877A
******************************************************************************/

#include "../MCAL/GPIO/GPIO_interface.h"
#include "../MCAL/ADC/ADC_Interface.h"
#include "../MCAL/UART/UART_Interface.h"

#include "../HAL/LED/LED_interface.h"
#include "../HAL/SWITCH/SWITCH_interface.h"

#include "../SERVICES/STD_TYPES.h"

/* ========================== PIN MAPPING ================================== */

/* ADC */
#define VOLTAGE_ADC_CHANNEL          ADC_CHANNEL_0     /* RA0 / AN0 */

/*
 * ADC Reference = 5V
 * 1V => (1 / 5) * 1023 = 204.6
 * ADC values 0..204 are below 1V
 */
#define VOLTAGE_1V_THRESHOLD_ADC     205U

/* Inputs */
#define PIR_INPUT_PORT               GPIO_PORTB
#define PIR_INPUT_PIN                GPIO_PIN1         /* RB1 */

#define LOCK_INPUT_PORT              GPIO_PORTB
#define LOCK_INPUT_PIN               GPIO_PIN2         /* RB2 */

#define EXTRA_INPUT_PORT             GPIO_PORTD
#define EXTRA_INPUT_PIN              GPIO_PIN4         /* RD4 */

#define VOLTAGE_INPUT_PORT           GPIO_PORTA
#define VOLTAGE_INPUT_PIN            GPIO_PIN0         /* RA0 / AN0 */

/* Outputs */
#define LOCK_OUTPUT_PORT             GPIO_PORTD
#define LOCK_OUTPUT_PIN              GPIO_PIN0         /* RD0 */

#define ALARM_OUTPUT_PORT            GPIO_PORTD
#define ALARM_OUTPUT_PIN             GPIO_PIN1         /* RD1 */

#define VOLTAGE_OUTPUT_PORT          GPIO_PORTD
#define VOLTAGE_OUTPUT_PIN           GPIO_PIN2         /* RD2 */

#define PIR_LED_PORT                 GPIO_PORTD
#define PIR_LED_PIN                  GPIO_PIN3         /* RD3 */

/* UART pins */
#define UART_TX_PORT                 GPIO_PORTC
#define UART_TX_PIN                  GPIO_PIN6         /* RC6 / TX */

#define UART_RX_PORT                 GPIO_PORTC
#define UART_RX_PIN                  GPIO_PIN7         /* RC7 / RX */

/* ========================== GLOBAL VARIABLES ============================= */

static u8  rb1_state = 0;
static u8  rb2_state = 0;
static u8  rd4_state = 0;
static u16 adc_value = 0;

/* ========================== FUNCTION PROTOTYPES =========================== */

static void System_Init(void);
static void Read_Inputs(void);
static void Apply_Output_Logic(void);
static void Send_ADC_UART(void);

/* ========================== MAIN ========================================= */

void main(void)
{
    System_Init();

    while(1)
    {
        Read_Inputs();
        Apply_Output_Logic();
        Send_ADC_UART();

        Delay_ms(500);
    }
}

/* ========================== SYSTEM INIT ================================== */

static void System_Init(void)
{
    /* ================= Inputs ================= */

    SWITCH_Init(PIR_INPUT_PORT, PIR_INPUT_PIN);       /* RB1 input */
    SWITCH_Init(LOCK_INPUT_PORT, LOCK_INPUT_PIN);     /* RB2 input */
    SWITCH_Init(EXTRA_INPUT_PORT, EXTRA_INPUT_PIN);   /* RD4 input */

    GPIO_SetPinDirection(VOLTAGE_INPUT_PORT,
                         VOLTAGE_INPUT_PIN,
                         GPIO_INPUT);                 /* RA0 / AN0 input */

    /* ================= Outputs ================ */

    GPIO_SetPinDirection(LOCK_OUTPUT_PORT,
                         LOCK_OUTPUT_PIN,
                         GPIO_OUTPUT);                /* RD0 output */

    GPIO_SetPinDirection(ALARM_OUTPUT_PORT,
                         ALARM_OUTPUT_PIN,
                         GPIO_OUTPUT);                /* RD1 output */

    GPIO_SetPinDirection(VOLTAGE_OUTPUT_PORT,
                         VOLTAGE_OUTPUT_PIN,
                         GPIO_OUTPUT);                /* RD2 output */

    LED_Init(PIR_LED_PORT, PIR_LED_PIN);              /* RD3 LED only */

    /* ================= UART Pins =============== */

    GPIO_SetPinDirection(UART_TX_PORT,
                         UART_TX_PIN,
                         GPIO_OUTPUT);                /* RC6 / TX */

    GPIO_SetPinDirection(UART_RX_PORT,
                         UART_RX_PIN,
                         GPIO_INPUT);                 /* RC7 / RX */

    /* ================= Initial States ========== */

    GPIO_SetPinValue(LOCK_OUTPUT_PORT,
                     LOCK_OUTPUT_PIN,
                     GPIO_LOW);                       /* RD0 LOW */

    GPIO_SetPinValue(ALARM_OUTPUT_PORT,
                     ALARM_OUTPUT_PIN,
                     GPIO_LOW);                       /* RD1 LOW */

    GPIO_SetPinValue(VOLTAGE_OUTPUT_PORT,
                     VOLTAGE_OUTPUT_PIN,
                     GPIO_LOW);                       /* RD2 LOW */

    LED_Off(PIR_LED_PORT, PIR_LED_PIN);               /* RD3 LOW */

    /* ================= Drivers Init ============ */

    ADC_Init();
    UART_Init();
}

/* ========================== READ INPUTS ================================== */

static void Read_Inputs(void)
{
    rb1_state = SWITCH_GetState(PIR_INPUT_PORT, PIR_INPUT_PIN);
    rb2_state = SWITCH_GetState(LOCK_INPUT_PORT, LOCK_INPUT_PIN);
    rd4_state = SWITCH_GetState(EXTRA_INPUT_PORT, EXTRA_INPUT_PIN);

    adc_value = ADC_ReadChannel(VOLTAGE_ADC_CHANNEL);
}

/* ========================== APPLY LOGIC ================================== */

static void Apply_Output_Logic(void)
{
    /*
     * Same original logic:
     *
     * If RB1 = 1:
     *      RD3 = HIGH
     *      RD0 = HIGH
     *      RD1 = HIGH
     *
     * Else if RB2 = 1 OR RD4 = 1:
     *      RD3 = LOW
     *      RD0 = HIGH
     *      RD1 = LOW
     *
     * Else:
     *      RD3 = LOW
     *      RD0 = LOW
     *      RD1 = LOW
     */

    if(rb1_state == GPIO_HIGH)
    {
        LED_On(PIR_LED_PORT, PIR_LED_PIN);                         /* RD3 */

        GPIO_SetPinValue(LOCK_OUTPUT_PORT,
                         LOCK_OUTPUT_PIN,
                         GPIO_HIGH);                               /* RD0 */

        GPIO_SetPinValue(ALARM_OUTPUT_PORT,
                         ALARM_OUTPUT_PIN,
                         GPIO_HIGH);                               /* RD1 */
    }
    else if((rb2_state == GPIO_HIGH) || (rd4_state == GPIO_HIGH))
    {
        LED_Off(PIR_LED_PORT, PIR_LED_PIN);                        /* RD3 */

        GPIO_SetPinValue(LOCK_OUTPUT_PORT,
                         LOCK_OUTPUT_PIN,
                         GPIO_HIGH);                               /* RD0 */

        GPIO_SetPinValue(ALARM_OUTPUT_PORT,
                         ALARM_OUTPUT_PIN,
                         GPIO_LOW);                                /* RD1 */
    }
    else
    {
        LED_Off(PIR_LED_PORT, PIR_LED_PIN);                        /* RD3 */

        GPIO_SetPinValue(LOCK_OUTPUT_PORT,
                         LOCK_OUTPUT_PIN,
                         GPIO_LOW);                                /* RD0 */

        GPIO_SetPinValue(ALARM_OUTPUT_PORT,
                         ALARM_OUTPUT_PIN,
                         GPIO_LOW);                                /* RD1 */
    }

    /*
     * Voltage logic:
     * ADC < 205  => RA0 voltage < 1V  => RD2 HIGH
     * ADC >= 205 => RA0 voltage >= 1V => RD2 LOW
     */

    if(adc_value < VOLTAGE_1V_THRESHOLD_ADC)
    {
        GPIO_SetPinValue(VOLTAGE_OUTPUT_PORT,
                         VOLTAGE_OUTPUT_PIN,
                         GPIO_HIGH);                               /* RD2 */
    }
    else
    {
        GPIO_SetPinValue(VOLTAGE_OUTPUT_PORT,
                         VOLTAGE_OUTPUT_PIN,
                         GPIO_LOW);                                /* RD2 */
    }
}

/* ========================== UART SEND ==================================== */

static void Send_ADC_UART(void)
{
    /*
     * Send ADC value as 2 binary bytes:
     * First byte  = high byte
     * Second byte = low byte
     */

    UART_SendByte((u8)(adc_value >> 8));
    UART_SendByte((u8)(adc_value & 0xFF));
}

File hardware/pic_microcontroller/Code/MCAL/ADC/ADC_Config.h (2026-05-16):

/*******************************************************************************
 * File:    ADC_Config.h
 * Author:  Embedded Systems Engineer
 * Date:    2026
 * Device:  PIC16F877A
 * Compiler: mikroC PRO for PIC
 *
 * Description:
 *     ADC Configuration File - Contains all user-configurable settings for
 *     the ADC module. Modify these macros to customize ADC behavior.
 *
 * Notes:
 *     - This file contains ONLY configuration options
 *     - All settings are compile-time configurable
 *     - Fosc = 16MHz for this configuration
 ******************************************************************************/

#ifndef ADC_CONFIG_H
#define ADC_CONFIG_H

/*******************************************************************************
 * ADC CLOCK CONFIGURATION
 *
 * Select ADC conversion clock based on device frequency (16MHz)
 * TAD must be >= 1.6µs for correct conversion
 *
 * Options:
 *   ADC_FOSC_DIV_2   -> TAD = 2 * TOSC = 2 * 62.5ns = 125ns   (TOO FAST!)
 *   ADC_FOSC_DIV_8   -> TAD = 8 * TOSC = 8 * 62.5ns = 500ns   (TOO FAST!)
 *   ADC_FOSC_DIV_32  -> TAD = 32 * TOSC = 32 * 62.5ns = 2µs   (GOOD)
 *   ADC_RC_CLOCK     -> TAD = 2-6µs (typical 4µs)             (GOOD)
 *
 * For 16MHz, use FOSC/32 or RC Clock
 ******************************************************************************/
#define ADC_CLOCK_SELECTION     ADC_FOSC_DIV_32     // 2µs TAD @ 16MHz

/* ADC Clock Options */
#define ADC_FOSC_DIV_2          0x00    // ADCS1:ADCS0 = 00
#define ADC_FOSC_DIV_8          0x01    // ADCS1:ADCS0 = 01
#define ADC_FOSC_DIV_32         0x02    // ADCS1:ADCS0 = 10
#define ADC_RC_CLOCK            0x03    // ADCS1:ADCS0 = 11

/*******************************************************************************
 * ADC VOLTAGE REFERENCE CONFIGURATION
 *
 * Configure voltage reference sources for ADC conversions
 * VREF+ (high reference) and VREF- (low reference)
 ******************************************************************************/
#define ADC_VREF_CONFIG         ADC_VREF_VDD_VSS    // VDD and VSS references

/* Voltage Reference Options */
#define ADC_VREF_VDD_VSS        0x00    // VREF+ = VDD, VREF- = VSS (most common)
#define ADC_VREF_VDD_VREF       0x01    // VREF+ = VDD, VREF- = RA2/AN2/VREF-
#define ADC_VREF_VREFP_VSS      0x02    // VREF+ = RA3/AN3/VREF+, VREF- = VSS
#define ADC_VREF_VREFP_VREF     0x03    // VREF+ = RA3/AN3/VREF+, VREF- = RA2/AN2/VREF-

/*******************************************************************************
 * ADC RESULT JUSTIFICATION
 *
 * Configure how the 10-bit result is stored in the 16-bit register pair
 *
 * RIGHT JUSTIFIED: [ADRESH: 0000 00xx][ADRESL: xxxx xxxx]
 * LEFT JUSTIFIED:  [ADRESH: xxxx xxxx][ADRESL: xx00 0000]
 ******************************************************************************/
#define ADC_RESULT_FORMAT       ADC_RIGHT_JUSTIFIED

/* Result Format Options */
#define ADC_RIGHT_JUSTIFIED     0x01    // Right justified (most common for 10-bit)
#define ADC_LEFT_JUSTIFIED      0x00    // Left justified

/*******************************************************************************
 * ANALOG CHANNEL CONFIGURATION
 *
 * Configure which pins are analog inputs (A) and which are digital I/O (D)
 * PIC16F877A has 8 analog channels: AN0-AN7
 *
 * PCFG[3:0] bits determine the configuration
 * Example: 0x06 = All pins digital except AN0
 ******************************************************************************/
#define ADC_PORT_CONFIG         0x0E    // AN0 analog only, other AN pins digital

/* Common Port Configurations */
#define ADC_ALL_ANALOG          0x00    // AN0-AN7 all analog, VREF+ = VDD, VREF- = VSS
#define ADC_AN0_TO_AN4_ANALOG   0x04    // AN0-AN4 analog, AN5-AN7 digital
#define ADC_AN0_TO_AN2_ANALOG   0x02    // AN0-AN2 analog, rest digital
#define ADC_ALL_DIGITAL         0x06    // All digital I/O

/*******************************************************************************
 * ADC ACQUISITION TIME CONFIGURATION
 *
 * Minimum acquisition time after channel selection before starting conversion
 * Based on datasheet equation: TACQ = TAMP + TC + TCOFF
 *
 * At 16MHz with Fosc/32: Typical TACQ ~20µs for Rs = 10k?
 * Delay value is implementation-dependent (use delay_us() in code)
 ******************************************************************************/
#define ADC_ACQUISITION_DELAY_US    20  // Acquisition delay in microseconds

#endif  // ADC_CONFIG_H

/*******************************************************************************
 * END OF FILE
 ******************************************************************************/

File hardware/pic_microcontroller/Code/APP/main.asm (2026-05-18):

_main:

;main.c,77 :: 		void main(void)
;main.c,79 :: 		System_Init();
	CALL       main_System_Init+0
;main.c,81 :: 		while(1)
L_main0:
;main.c,83 :: 		Read_Inputs();
	CALL       main_Read_Inputs+0
;main.c,84 :: 		Apply_Output_Logic();
	CALL       main_Apply_Output_Logic+0
;main.c,85 :: 		Send_ADC_UART();
	CALL       main_Send_ADC_UART+0
;main.c,87 :: 		Delay_ms(500);
	MOVLW      11
	MOVWF      R11+0
	MOVLW      38
	MOVWF      R12+0
	MOVLW      93
	MOVWF      R13+0
L_main2:
	DECFSZ     R13+0, 1
	GOTO       L_main2
	DECFSZ     R12+0, 1
	GOTO       L_main2
	DECFSZ     R11+0, 1
	GOTO       L_main2
	NOP
	NOP
;main.c,88 :: 		}
	GOTO       L_main0
;main.c,89 :: 		}
L_end_main:
	GOTO       $+0
; end of _main

main_System_Init:

;main.c,93 :: 		static void System_Init(void)
;main.c,97 :: 		SWITCH_Init(PIR_INPUT_PORT, PIR_INPUT_PIN);       /* RB1 input */
	MOVLW      1
	MOVWF      FARG_SWITCH_Init_Port+0
	MOVLW      1
	MOVWF      FARG_SWITCH_Init_Pin+0
	CALL       _SWITCH_Init+0
;main.c,98 :: 		SWITCH_Init(LOCK_INPUT_PORT, LOCK_INPUT_PIN);     /* RB2 input */
	MOVLW      1
	MOVWF      FARG_SWITCH_Init_Port+0
	MOVLW      2
	MOVWF      FARG_SWITCH_Init_Pin+0
	CALL       _SWITCH_Init+0
;main.c,99 :: 		SWITCH_Init(EXTRA_INPUT_PORT, EXTRA_INPUT_PIN);   /* RD4 input */
	MOVLW      3
	MOVWF      FARG_SWITCH_Init_Port+0
	MOVLW      4
	MOVWF      FARG_SWITCH_Init_Pin+0
	CALL       _SWITCH_Init+0
;main.c,101 :: 		GPIO_SetPinDirection(VOLTAGE_INPUT_PORT,
	CLRF       FARG_GPIO_SetPinDirection_Port+0
;main.c,102 :: 		VOLTAGE_INPUT_PIN,
	CLRF       FARG_GPIO_SetPinDirection_Pin+0
;main.c,103 :: 		GPIO_INPUT);                 /* RA0 / AN0 input */
	MOVLW      1
	MOVWF      FARG_GPIO_SetPinDirection_Direction+0
	CALL       _GPIO_SetPinDirection+0
;main.c,107 :: 		GPIO_SetPinDirection(LOCK_OUTPUT_PORT,
	MOVLW      3
	MOVWF      FARG_GPIO_SetPinDirection_Port+0
;main.c,108 :: 		LOCK_OUTPUT_PIN,
	CLRF       FARG_GPIO_SetPinDirection_Pin+0
;main.c,109 :: 		GPIO_OUTPUT);                /* RD0 output */
	CLRF       FARG_GPIO_SetPinDirection_Direction+0
	CALL       _GPIO_SetPinDirection+0
;main.c,111 :: 		GPIO_SetPinDirection(ALARM_OUTPUT_PORT,
	MOVLW      3
	MOVWF      FARG_GPIO_SetPinDirection_Port+0
;main.c,112 :: 		ALARM_OUTPUT_PIN,
	MOVLW      1
	MOVWF      FARG_GPIO_SetPinDirection_Pin+0
;main.c,113 :: 		GPIO_OUTPUT);                /* RD1 output */
	CLRF       FARG_GPIO_SetPinDirection_Direction+0
	CALL       _GPIO_SetPinDirection+0
;main.c,115 :: 		GPIO_SetPinDirection(VOLTAGE_OUTPUT_PORT,
	MOVLW      3
	MOVWF      FARG_GPIO_SetPinDirection_Port+0
;main.c,116 :: 		VOLTAGE_OUTPUT_PIN,
	MOVLW      2
	MOVWF      FARG_GPIO_SetPinDirection_Pin+0
;main.c,117 :: 		GPIO_OUTPUT);                /* RD2 output */
	CLRF       FARG_GPIO_SetPinDirection_Direction+0
	CALL       _GPIO_SetPinDirection+0
;main.c,119 :: 		LED_Init(PIR_LED_PORT, PIR_LED_PIN);              /* RD3 LED only */
	MOVLW      3
	MOVWF      FARG_LED_Init_Port+0
	MOVLW      3
	MOVWF      FARG_LED_Init_Pin+0
	CALL       _LED_Init+0
;main.c,123 :: 		GPIO_SetPinDirection(UART_TX_PORT,
	MOVLW      2
	MOVWF      FARG_GPIO_SetPinDirection_Port+0
;main.c,124 :: 		UART_TX_PIN,
	MOVLW      6
	MOVWF      FARG_GPIO_SetPinDirection_Pin+0
;main.c,125 :: 		GPIO_OUTPUT);                /* RC6 / TX */
	CLRF       FARG_GPIO_SetPinDirection_Direction+0
	CALL       _GPIO_SetPinDirection+0
;main.c,127 :: 		GPIO_SetPinDirection(UART_RX_PORT,
	MOVLW      2
	MOVWF      FARG_GPIO_SetPinDirection_Port+0
;main.c,128 :: 		UART_RX_PIN,
	MOVLW      7
	MOVWF      FARG_GPIO_SetPinDirection_Pin+0
;main.c,129 :: 		GPIO_INPUT);                 /* RC7 / RX */
	MOVLW      1
	MOVWF      FARG_GPIO_SetPinDirection_Direction+0
	CALL       _GPIO_SetPinDirection+0
;main.c,133 :: 		GPIO_SetPinValue(LOCK_OUTPUT_PORT,
	MOVLW      3
	MOVWF      FARG_GPIO_SetPinValue_Port+0
;main.c,134 :: 		LOCK_OUTPUT_PIN,
	CLRF       FARG_GPIO_SetPinValue_Pin+0
;main.c,135 :: 		GPIO_LOW);                       /* RD0 LOW */
	CLRF       FARG_GPIO_SetPinValue_Value+0
	CALL       _GPIO_SetPinValue+0
;main.c,137 :: 		GPIO_SetPinValue(ALARM_OUTPUT_PORT,
	MOVLW      3
	MOVWF      FARG_GPIO_SetPinValue_Port+0
;main.c,138 :: 		ALARM_OUTPUT_PIN,
	MOVLW      1
	MOVWF      FARG_GPIO_SetPinValue_Pin+0
;main.c,139 :: 		GPIO_LOW);                       /* RD1 LOW */
	CLRF       FARG_GPIO_SetPinValue_Value+0
	CALL       _GPIO_SetPinValue+0
;main.c,141 :: 		GPIO_SetPinValue(VOLTAGE_OUTPUT_PORT,
	MOVLW      3
	MOVWF      FARG_GPIO_SetPinValue_Port+0
;main.c,142 :: 		VOLTAGE_OUTPUT_PIN,
	MOVLW      2
	MOVWF      FARG_GPIO_SetPinValue_Pin+0
;main.c,143 :: 		GPIO_LOW);                       /* RD2 LOW */
	CLRF       FARG_GPIO_SetPinValue_Value+0
	CALL       _GPIO_SetPinValue+0
;main.c,145 :: 		LED_Off(PIR_LED_PORT, PIR_LED_PIN);               /* RD3 LOW */
	MOVLW      3
	MOVWF      FARG_LED_Off_Port+0
	MOVLW      3
	MOVWF      FARG_LED_Off_Pin+0
	CALL       _LED_Off+0
;main.c,149 :: 		ADC_Init();
	CALL       _ADC_Init+0
;main.c,150 :: 		UART_Init();
	CALL       _UART_Init+0
;main.c,151 :: 		}
L_end_System_Init:
	RETURN
; end of main_System_Init

main_Read_Inputs:

;main.c,155 :: 		static void Read_Inputs(void)
;main.c,157 :: 		rb1_state = SWITCH_GetState(PIR_INPUT_PORT, PIR_INPUT_PIN);
	MOVLW      1
	MOVWF      FARG_SWITCH_GetState_Port+0
	MOVLW      1
	MOVWF      FARG_SWITCH_GetState_Pin+0
	CALL       _SWITCH_GetState+0
	MOVF       R0+0, 0
	MOVWF      main_rb1_state+0
;main.c,158 :: 		rb2_state = SWITCH_GetState(LOCK_INPUT_PORT, LOCK_INPUT_PIN);
	MOVLW      1
	MOVWF      FARG_SWITCH_GetState_Port+0
	MOVLW      2
	MOVWF      FARG_SWITCH_GetState_Pin+0
	CALL       _SWITCH_GetState+0
	MOVF       R0+0, 0
	MOVWF      main_rb2_state+0
;main.c,159 :: 		rd4_state = SWITCH_GetState(EXTRA_INPUT_PORT, EXTRA_INPUT_PIN);
	MOVLW      3
	MOVWF      FARG_SWITCH_GetState_Port+0
	MOVLW      4
	MOVWF      FARG_SWITCH_GetState_Pin+0
	CALL       _SWITCH_GetState+0
	MOVF       R0+0, 0
	MOVWF      main_rd4_state+0
;main.c,161 :: 		adc_value = ADC_ReadChannel(VOLTAGE_ADC_CHANNEL);
	CLRF       FARG_ADC_ReadChannel_channel+0
	CALL       _ADC_ReadChannel+0
	MOVF       R0+0, 0
	MOVWF      main_adc_value+0
;main.c,162 :: 		}
L_end_Read_Inputs:
	RETURN
; end of main_Read_Inputs

main_Apply_Output_Logic:
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

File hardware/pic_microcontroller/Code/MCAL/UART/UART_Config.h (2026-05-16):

/******************************************************************************
 * File:    UART_Config.h
 * Author:  Embedded Systems Engineer
 * Date:    2026
 * Description: UART Configuration File for PIC16F877A
 *              Contains all user-configurable settings for UART driver
 * MCU:     PIC16F877A
 * Clock:   16MHz Crystal Oscillator
 * Compiler: mikroC PRO for PIC
 ******************************************************************************/

#ifndef UART_CONFIG_H
#define UART_CONFIG_H

/******************************************************************************
 *                      SYSTEM CONFIGURATION
 ******************************************************************************/
#define F_CPU                   16000000UL      // 16MHz system clock

/******************************************************************************
 *                      BAUD RATE CONFIGURATION
 ******************************************************************************/
/*
 * Common Baud Rates for 16MHz:
 * 9600   -> SPBRG = 25  (BRGH = 1, Error = 0.16%)
 * 19200  -> SPBRG = 12  (BRGH = 1, Error = 0.16%)
 * 38400  -> SPBRG = 25  (BRGH = 0, Error = 0.16%)
 * 57600  -> SPBRG = 3   (BRGH = 1, Error = 0%)
 * 115200 -> SPBRG = 8   (BRGH = 0, Error = 3.55%)
 */
#define UART_BAUD_RATE          9600            // Default baud rate

/******************************************************************************
 *                      UART MODE CONFIGURATION
 ******************************************************************************/
/* UART Communication Mode */
#define UART_MODE_ASYNC         0               // Asynchronous mode
#define UART_MODE_SYNC          1               // Synchronous mode
#define UART_MODE               UART_MODE_ASYNC // Selected mode

/* Baud Rate Speed Selection */
#define UART_SPEED_LOW          0               // Low speed (BRGH = 0)
#define UART_SPEED_HIGH         1               // High speed (BRGH = 1)
#define UART_SPEED              UART_SPEED_HIGH // Selected speed

/******************************************************************************
 *                      TRANSMISSION CONFIGURATION
 ******************************************************************************/
/* Transmitter Enable/Disable */
#define UART_TX_ENABLE          1               // 1 = Enable TX, 0 = Disable
#define UART_TX_DISABLE         0

/* Receiver Enable/Disable */
#define UART_RX_ENABLE          1               // 1 = Enable RX, 0 = Disable
#define UART_RX_DISABLE         0

/* Data Bits Configuration */
#define UART_DATA_BITS_8        0               // 8-bit transmission
#define UART_DATA_BITS_9        1               // 9-bit transmission
#define UART_DATA_BITS          UART_DATA_BITS_8

/******************************************************************************
 *                      INTERRUPT CONFIGURATION
 ******************************************************************************/
/* UART Interrupt Enable/Disable */
#define UART_INTERRUPT_ENABLE   0               // 1 = Enable, 0 = Disable
#define UART_INTERRUPT_DISABLE  0

/* TX Interrupt Enable */
#define UART_TX_INT_ENABLE      0               // 1 = Enable TX interrupt

/* RX Interrupt Enable */
#define UART_RX_INT_ENABLE      0               // 1 = Enable RX interrupt

/******************************************************************************
 *                      RECEIVE MODE CONFIGURATION
 ******************************************************************************/
/* Continuous Receive Mode */
#define UART_CONT_RX_ENABLE     1               // 1 = Continuous receive mode
#define UART_CONT_RX_DISABLE    0

/******************************************************************************
 *                      ERROR HANDLING CONFIGURATION
 ******************************************************************************/
/* Enable Error Detection and Recovery */
#define UART_ERROR_DETECT       1               // 1 = Enable error detection
#define UART_AUTO_RECOVERY      1               // 1 = Auto recover from errors

/******************************************************************************
 *                      BUFFER CONFIGURATION
 ******************************************************************************/
/* String Buffer Size */
#define UART_STRING_BUFFER_SIZE 64              // Maximum string length

/******************************************************************************
 *                      PIN CONFIGURATION
 ******************************************************************************/
/* UART uses RC6 (TX) and RC7 (RX) pins - configured automatically by SPEN bit */
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

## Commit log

2026-05-15 Add schematics diagrams and reference papers
2026-05-16 Update PIC drivers and add UART ADC transmission
2026-05-18 Update PIC microcontroller code
    [MyProject.cfg]
2026-05-24 Add PCB design and manufacturing files
    [Bank_Security_PCB (1).kicad_pcb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]
